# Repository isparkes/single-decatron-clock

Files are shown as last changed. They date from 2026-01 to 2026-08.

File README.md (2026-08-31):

# Single Decatron Clock Firmware

Firmware for a clock built around a single Decatron (Dekatron) cold-cathode
gas-discharge tube — a 1950s-era 30-position counting tube repurposed here as
an analogue-style hours/minutes/seconds display.

Current software version: `4`

See [`SPECIFICATION.md`](SPECIFICATION.md) for the full hardware/firmware
specification and [`DecatronClockFirmware/USER_MANUAL.md`](DecatronClockFirmware/USER_MANUAL.md)
for end-user documentation of the web interface and configuration options.

## Hardware overview

An ESP8266 (Wemos D1 Mini) drives a Decatron tube through a two-guide
stepping scheme, decoding a rotary glow position from three interrupt phases
per step (30 pin-steps per revolution). The device runs as either a
standalone clock (NTP with DS1307 RTC fallback) or as an I2C slave to a
master clock — in this repo's current configuration, an
[ENIAC Nixie clock](../eniac-firmware) — which pushes wall-clock time and
blanking state once per second.

## Highlights

Some of the more interesting problems this firmware solves:

- **Single-interrupt display multiplexing with per-dot brightness weighting**
  — one `timer1` ISR steps the tube through all 30 positions, comparing the
  current pin against three independently tracked display targets
  (hours/minutes/seconds) and re-arming itself with a dwell count scaled 60×,
  15×, or 5× the base "off" duration. Three dots glow simultaneously at
  three distinct brightness levels from a single timer, with no separate
  PWM channel per dot.
- **Self-homing via a swappable ISR** — at boot the firmware runs a slow
  *scanning* interrupt handler that free-runs the tube until a physical index
  sense pin fires, then hot-swaps `timer1`'s callback to the normal *display*
  handler. The index trigger continues correcting drift at every revolution,
  so the tube's absolute glow position never has to be assumed — it's always
  physically re-derived.
- **Graceful multi-source time arbitration** — an I2C slave callback
  (`ICACHE_RAM_ATTR`, interrupt-context, exactly 4 bytes, no blocking) accepts
  push updates from a master clock once per second and overrides local state;
  if a second passes with no packet, the display falls back to its own
  NTP-derived clock and locally computed blanking without a hiccup. All the
  actual decision logic runs in the main loop — the ISR only stashes bytes
  into `volatile` buffers.
- **Layered blanking with escalating button override** — day/week schedule,
  PIR motion timeout, and an explicit remote "blanked" command from the I2C
  master all compete to blank the tube, and a single button independently
  suppresses all of them: press once to hold the display on for a minute,
  twice in quick succession for an hour, three times for a day, with the
  press count decoded from timing between presses.
- **Perceptually-tuned spin-up ramp** — coming out of blanking, the HV supply
  re-enables and the multiplex dwell count ramps back down from a 250,000-count
  "off" dwell to a 1,000-count "on" dwell at one of three configurable rates,
  so the tube visibly fades in rather than snapping to full brightness.
- **Self-describing status page** — the root web page live-scans all 128 I2C
  addresses to report connected peripherals, and encodes overall device
  health (WiFi / NTP / SPIFFS / OTA-available / auth / debug) as a compact
  single-character status string, alongside uptime and tube-on-time
  statistics persisted to SPIFFS.
- **Zero-touch provisioning and recovery** — first boot (or a factory reset
  triggered by holding the button at power-up) opens a WiFiManager captive
  portal; once configured, the device is reachable by mDNS hostname, supports
  OTA updates gated on available flash headroom, and independently exposes
  WiFi-only, config-only, and full-factory reset endpoints.

## Repository layout

| Path | Description |
|---|---|
| [`DecatronClockFirmware`](DecatronClockFirmware) | Main Arduino sketch and supporting modules (display ISR, I2C slave, web server, NTP, RTC, SPIFFS config, button handling, debug logging). |
| [`decatron_clock_test`](decatron_clock_test) | Standalone bench sketch for exercising the Decatron tube stepping logic in isolation. |

## Building

This is an Arduino sketch targeting the ESP8266 core.

```bash
# Board: Lolin/Wemos D1 Mini, 160 MHz, Flash 4MB (FS: 2MB, OTA: ~1MB)
# Open DecatronClockFirmware/DecatronClockFirmware.ino in the Arduino IDE
# or build with arduino-cli:
arduino-cli compile --fqbn esp8266:esp8266:d1_mini DecatronClockFirmware
arduino-cli upload  --fqbn esp8266:esp8266:d1_mini -p <port> DecatronClockFirmware
```

Dependencies: [`TimeLib`](https://github.com/michaelmargolis/arduino_time),
[`WiFiManager`](https://github.com/tzapu/WiFiManager), and the ESP8266
Arduino core (`ESP8266WiFi`, `ESP8266WebServer`, `ESP8266HTTPUpdateServer`,
`ESP8266mDNS`, `LittleFS`/`SPIFFS`, `Wire`).

## Documentation

- [`SPECIFICATION.md`](SPECIFICATION.md) — full hardware/firmware specification, including the I2C protocol, GPIO map, and configuration parameters
- [`DecatronClockFirmware/USER_MANUAL.md`](DecatronClockFirmware/USER_MANUAL.md) / [`USER_MANUAL.html`](DecatronClockFirmware/USER_MANUAL.html) — end-user manual

## License

This project is licensed under a strict Attribution-NonCommercial license — see
[`LICENSE`](LICENSE) for the full text. In short: attribution to Ian Sparkes is required, and
commercial use is not permitted without a separate written license.

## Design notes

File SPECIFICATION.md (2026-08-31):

# Single Decatron Clock Firmware Specification

**Version:** 4
**Platform:** ESP8266 (Lolin/Wemos D1 Mini)
**Framework:** Arduino (ESP8266 Arduino Core)

---

## 1. Overview

The Single Decatron Clock firmware drives a single Decatron (Dekatron) gas-discharge tube clock. A Decatron is a cold-cathode tube with 30 cathode positions (10 main cathodes plus 20 guide cathodes). The tube glows at one or more positions simultaneously; display intensity is controlled by the dwell time of the interrupt-driven scanning loop.

The firmware operates in two modes:

- **Standalone mode** — the device sources its own time from NTP over WiFi, with fallback to an onboard DS1307 RTC.
- **I2C slave mode (current)** — the device acts as an I2C slave to a master clock (e.g. Eniac/LTC-ESP32). Time, blanking state, and display mode are pushed to it once per second. NTP remains active as a fallback time source; the RTC is not accessible while the I2C bus is in slave mode.

### 1.1 Key Features

- Decatron tube display: simultaneous hours, minutes, and seconds dots at configurable brightnesses
- I2C slave receiver: accepts time and control data from a master clock once per second
- NTP time synchronisation over WiFi (fallback when no I2C master is present)
- Configurable day/week blanking schedules
- PIR motion detection with configurable timeout
- Button-triggered blanking suppression (1 minute / 1 hour / 1 day)
- Adaptive brightness via LDR (light-dependent resistor)
- Optional seconds flashing
- Web configuration interface with HTTP Basic Authentication
- Over-the-air (OTA) firmware updates
- mDNS hostname resolution
- SPIFFS-backed persistent configuration and uptime statistics
- Factory reset via button held at boot

---

## 2. Hardware

### 2.1 Microcontroller

| Component | Specification |
|---|---|
| MCU | ESP8266 (Lolin/Wemos D1 Mini) |
| Clock | 160 MHz |
| Flash | 4 MB (FS: 2 MB, OTA: ~1 MB) |
| Framework | Arduino (ESP8266 Arduino Core) |

### 2.2 GPIO Assignments

| Signal | Pin | GPIO | Description |
|---|-----|---|---|
| Guide1 | D7 | GPIO13 | Decatron guide 1 (G1) |
| Guide2 | D8 | GPIO15 | Decatron guide 2 (G2) |
| Index | D6 | GPIO12 | Decatron index sense (K0 high when glow at K0) |
| HVEnable | D5 | GPIO14 | High-voltage supply enable (HIGH = on) |
| PIR | D4 | GPIO2 | PIR motion sensor input |
| Button1 | D3 | GPIO0 | User input button (active low) |
| LDR | A0 | ADC0 | Light-dependent resistor (analogue) |
| I2C SDA | D2 | GPIO4 | I2C data (slave to master clock) |
| I2C SCL | D1 | GPIO5 | I2C clock (slave to master clock) |

> **Note:** In I2C slave mode the SDA/SCL pins (D2/D1) cannot simultaneously be used to communicate with the onboard RTC. The RTC is therefore bypassed.

### 2.3 Peripherals

| Peripheral | Interface | Address / Notes |
|---|---|---|
| DS1307 RTC | I2C | 0x68 — bypassed in slave mode |
| Master clock (Eniac) | I2C slave | 0x6A (106) — this device |
| LDR | Analogue | A0 |
| PIR sensor | Digital | D4, optional |

---

## 3. Display

### 3.1 Decatron Tube

A Decatron has 30 addressable positions driven via a two-guide stepping scheme. Each step consists of three phases:

| Phase | Guide1 | Guide2 | Effect |
|---|---|---|---|
| 0 | LOW | LOW | Resting (at current cathode) |
| 1 | HIGH | LOW | Step via G1 |
| 2 | LOW | HIGH | Step via G2 |

Three phase steps advance the glow by one main cathode position (1/10th of the tube). Ten main cathodes × 3 phases = 30 total pin-steps per revolution.

### 3.2 Display Values

Time is mapped to tube positions as follows:

| Value | Mapping | Tube position range |
|---|---|---|
| Hours | `((h % 12) * 60 + m) * 30.0 / 720` | 0–29 (12-hour) |
| Minutes | `m / 2` | 0–29 |
| Seconds | `s / 2` | 0–29 |

Three dots are shown simultaneously. Dwell-time weighting controls relative brightness:

| Dot | Multiplier (× base mux count) | Relative brightness |
|-----|---|---|
| Hours | 60× | Brightest |
| Minutes | 15× | Medium |
| Seconds | 5× | Dimmest |

The base mux count (`INT_MUX_COUNTS_ON = 1000`, units of 0.2 µs at TIM_DIV16 / 80 MHz) sets the off-state dwell; active positions dwell longer.

### 3.3 Startup Scan

On power-up the firmware runs a slow scanning interrupt (`displayUpdateScanning`) at `INT_MUX_COUNTS_OFF × 2` to locate the index mark and home the tube before switching to normal display.

### 3.4 Display Rotation

`current_config.displayRotate` (0–9) offsets the index correction point so the K0 position can be aligned to any desired clock position.

### 3.5 Seconds Flash

When `current_config.flashSeconds` is set:
- The minutes dot is hidden for the first 500 ms of each second.
- The seconds dot alternates on/off every 100 ms.

### 3.6 Blanking

When `blanked` is true the HV supply is disabled (`HVEnable = LOW`) and the mux count ramps up toward `INT_MUX_COUNTS_OFF`. When un-blanked, HV is enabled and the mux count ramps back down to `INT_MUX_COUNTS_ON` at a rate set by `spinUpVal`.

---

## 4. I2C Slave Protocol

The device listens at I2C address **106 (0x6A)** on SDA = D2 (GPIO4), SCL = D1 (GPIO5).

### 4.1 Receive Packet (master → slave)

Sent by the master once per second. Exactly 4 bytes:

| Byte | Field | Range | Description |
|---|---|---|---|
| 1 | Hours | 0–23 | Current hour (24-hour) |
| 2 | Minutes | 0–59 | Current minute |
| 3 | Seconds | 0–59 | Current second |
| 4 | Control | — | See below |

#### Control Byte

| Bit(s) | Mask | Field | Description |
|---|---|---|---|
| 0 | `0x01` | Blanked | 1 = master requests display blank |
| 1–4 | `0x1E` | Primary mode | Master's current display mode (reserved for future use) |
| 5–7 | — | Reserved | Ignored |

### 4.2 Behaviour on Receipt

The `onI2CReceive` callback (runs in interrupt context) stores the received bytes in volatile variables and sets `i2cDataReceived = true`. In the main loop, when the flag is set:

1. `displayHours`, `displayMinsPrep`, and `displaySecsPrep` are recalculated from the received h/m/s.
2. `blanked` is set from control bit 0, overriding any local NTP-based blanking decision.

### 4.3 Fallback

If no I2C packet has been received since the last second tick, the display continues to be driven by the NTP-derived internal time and local blanking logic.

---

## 5. Time Sources

### 5.1 Priority

| Priority | Source | Condition |
|---|---|---|
| 1 | I2C master | Packet received in current loop iteration |
| 2 | NTP | WiFi connected and NTP valid |
| 3 | Internal (TimeLib) | No connectivity; retains last set time |

### 5.2 RTC

A DS1307 RTC at I2C address 0x68 is supported in standalone mode only. While the I2C bus is configured as slave (address 0x6A), the device cannot act as I2C master and the RTC is bypassed (`useRTC = false`).

### 5.3 NTP

| Parameter | Default |
|---|---|
| NTP pool | Configured at first boot / via web UI |
| Update interval | Configurable |
| Timezone | POSIX TZ string, configurable |

NTP updates are requested at startup and periodically by the async NTP component. A successful update also sets the RTC in standalone mode.

---

## 6. Blanking

Blanking disables the HV supply and fades the mux count to `INT_MUX_COUNTS_OFF`. Multiple sources can independently trigger blanking.

### 6.1 Blanking Sources

| Source | Trigger | Notes |
|---|---|---|
| I2C master | Control byte bit 0 set | Overrides local logic immediately |
| Day/schedule | `current_config.dayBlanking` | See modes below |
| PIR timeout | No motion within `pirTimeout` seconds | When PIR sensor installed |
| Button suppression | Active suppress period | Overrides day/schedule and PIR |

### 6.2 Day Blanking Modes

| Value | Name | Description |
|---|---|---|
| 0 | Never | Always on (default) |
| 1 | Weekend | Blank all day Saturday and Sunday |
| 2 | Weekday | Blank all day Monday–Friday |
| 3 | Always | Always blank |
| 4 | Hours | Blank between `blankHourStart` and `blankHourEnd` every day |
| 5 | Weekend or Hours | Mode 4 on weekdays, mode 1 on weekends |
| 6 | Weekday or Hours | Mode 4 on weekends, mode 2 on weekdays |
| 7 | Weekend and Hours | Mode 4 only during weekends |
| 8 | Weekday and Hours | Mode 4 only during weekdays |

### 6.3 PIR Motion Detection

When a PIR sensor is installed, native day/schedule blanking is disabled. The tube blanks after `pirTimeout` seconds of no motion (default 300 s, range 60–3600 s). Motion is detected by counting consecutive loop iterations where the PIR pin is HIGH; at least half the impressions-per-second must be active to count as a valid detection.

### 6.4 Button Blanking Suppression

A button press during a blanked period suppresses blanking. Successive rapid presses increase the suppression duration:

| Presses | Duration |
|---|---|
| 1 | 1 minute |
| 2 | 1 hour |
| 3 | 1 day |

---

## 7. Configuration

### 7.1 Stored Parameters (SPIFFS)

| Parameter | Type | Default | Description |
|---|---|---|---|
| `ntpPool` | String | — | NTP server hostname |
| `ntpUpdateInterval` | int | — | NTP poll interval (s) |
| `tzs` | String | — | POSIX timezone string |
| `showSeconds` | bool | — | Show seconds dot |
| `flashSeconds` | bool | — | Flash seconds dot |
| `dayBlanking` | byte | 0 | Blanking schedule mode |
| `blankHourStart` | byte | 0 | Blanking start hour |
| `blankHourEnd` | byte | 7 | Blanking end hour |
| `pirTimeout` | int | 300 | PIR inactivity timeout (s) |
| `usePIRPullup` | bool | — | Enable PIR pin internal pull-up |
| `displayRotate` | byte | 0–9 | Index position offset |
| `spinUpSpeed` | byte | 1 | Spin-up speed (0=slow, 1=medium, 2=fast) |
| `webAuthentication` | bool | true | Require HTTP auth |
| `webUsername` | String | admin | Web UI username |
| `webPassword` | String | setup | Web UI password |
| `testMode` | bool | true | Enable test/diagnostic mode |

### 7.2 Persistent Statistics

| Field | Description |
|---|---|
| `uptimeMins` | Total uptime in minutes |
| `tubeOnTimeMins` | Minutes the tube has been unblanked |

Statistics are written to SPIFFS once per day and on explicit save.

### 7.3 Factory Reset

Factory reset is triggered by:
- Holding Button1 at boot.
- The `/resetall` or `/resetoptions` web endpoint.

Reset restores all parameters to defaults and saves to SPIFFS.

---

## 8. Web Interface

The device hosts an HTTP server on port 80. All pages except the root require HTTP Basic Authentication when enabled.

### 8.1 Endpoints

| Path | Description |
|---|---|
| `/` | Status and clock information |
| `/time` | Set time manually |
| `/resetoptions` | Reset configuration to defaults |
| `/resetwifi` | Clear WiFi credentials and restart |
| `/resetall` | Full factory reset |
| `/update` | OTA firmware upload (admin / update) |

### 8.2 mDNS

The device advertises itself via mDNS as `http://<hostname>.local` with an HTTP service on port 80.

---

## 9. WiFi

On first boot (or after a WiFi reset) the device starts a WiFi captive portal AP named **decatron** with passphrase **SetMeUp!**. The portal times out after 60 seconds. Once credentials are saved they are used on all subsequent boots. Auto-reconnect is enabled; a dropped connection is retried once per hour.

---

## 10. Firmware Updates

OTA updates are available at `/update` (credentials: admin / update) when the compiled sketch size is less than half the available flash. Updates are served via `ESP8266HTTPUpdateServer`.

---

## 11. Spin-Up Speeds

The mux count ramps from `INT_MUX_COUNTS_OFF` (250 000) down to `INT_MUX_COUNTS_ON` (1 000) at startup and after un-blanking. The ramp rate is controlled by `spinUpVal`:

| Mode | `spinUpVal` | Ramp character |
|---|---|---|
| Slow | 200 | Gradual |
| Medium (default) | 100 | Normal |
| Fast | 50 | Rapid |

---

## 12. Software Architecture

### 12.1 Interrupt Handler

`displayUpdate()` runs on `timer1` (TIM_DIV16, single-shot). Each call:
1. Advances `phaseStep` (0→1→2→0).
2. On phase rollover, advances `digitStep` (0–9).
3. Calls `G_step(phaseStep)` to assert Guide1/Guide2.
4. Compares `pinStep = digitStep * 3 + phaseStep` against the three display targets.
5. Sets the next timer alarm to the dwell count for the active dot (or the base count if none match).

`indexMarkTrigger()` fires on the falling edge of the Index pin and corrects `digitStep` to align the tube to `displayRotate`.

### 12.2 Main Loop Cadence

| Interval | Action |
|---|---|
| Every 10 ms | Main loop tick: handle web server, PIR sampling, flash logic, I2C data application, HV/mux ramp |
| Once per second | `performOncePerSecondProcessing`: blanking check, NTP poll, display value update |
| Once per minute | `performOncePerMinuteProcessing`: uptime stats, connectivity log |
| Once per hour | `performOncePerHourProcessing`: WiFi reconnect attempt |
| Once per day | `performOncePerDayProcessing`: save stats to SPIFFS |

### 12.3 I2C Slave Callback

`onI2CReceive(int numBytes)` runs in interrupt context (`ICACHE_RAM_ATTR`). It reads exactly 4 bytes into volatile buffers and sets `i2cDataReceived`. All non-trivial processing occurs in the main loop.

### 12.4 Component Files

| File | Responsibility |
|---|---|
| `DecatronClockFirmware.ino` | Main sketch: display ISR, setup, loop, time management, blanking, I2C slave |
| `ClockDefs.h` | Pin assignments, constants, blanking mode enums |
| `SPIFFS.cpp/h` | Persistent config and stats (ArduinoJson 5) |
| `ESP_DS1307.cpp/h` | DS1307 RTC driver (I2C master; unused in slave mode) |
| `NtpAsync.cpp/h` | Asynchronous NTP client |
| `HtmlServer.cpp/h` | HTTP server, OTA, mDNS, HTML helpers |
| `ClockUtils.cpp/h` | String/debug utilities |
| `ClockButton.cpp/h` | Debounced button handler |
| `DebugManager.cpp/h` | Serial debug output |

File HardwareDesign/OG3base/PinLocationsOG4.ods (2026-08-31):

 |  |  |  |  | Pin Unadjusted |  | Pin Adjusted
 |  |  | Radians | Rad Adj | X | Y | X | y | Pin | Function
1 | 0 | 0 | 0 | 0.392699081698724 | 0 | -8.75 | 3.34848003319454 | -8.08394590947376 | 1 | INDEX
2 | 1 | 45 | 0.785398163397448 | 1.17809724509617 | 6.18718433538229 | -6.18718433538229 | 8.08394590947376 | -3.34848003319454 | 2 | NC
3 | 2 | 90 | 1.5707963267949 | 1.96349540849362 | 8.75 | -5.35782974626967E-16 | 8.08394590947376 | 3.34848003319453 | 3 | ANODE
4 | 3 | 135 | 2.35619449019234 | 2.74889357189107 | 6.18718433538229 | 6.18718433538229 | 3.34848003319454 | 8.08394590947376 | 4 | G1
5 | 4 | 180 | 3.14159265358979 | 3.53429173528852 | 1.07156594925393E-15 | 8.75 | -3.34848003319453 | 8.08394590947376 | 5 | NC
6 | 5 | 225 | 3.92699081698724 | 4.31968989868597 | -6.18718433538229 | 6.18718433538229 | -8.08394590947376 | 3.34848003319453 | 6 | G2
7 | 6 | 270 | 4.71238898038469 | 5.10508806208341 | -8.75 | 1.6073489238809E-15 | -8.08394590947376 | -3.34848003319454 | 7 | NC
8 | 7 | 315 | 5.49778714378214 | 5.89048622548086 | -6.18718433538229 | -6.18718433538229 | -3.34848003319453 | -8.08394590947376 | 8 | K1-9
#pins | 8 |  |  | Deg per pin | 45
degrees rotated | 22.5
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

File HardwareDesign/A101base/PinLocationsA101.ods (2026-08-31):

 |  |  |  |  | Pin Unadjusted |  | Pin Adjusted
 |  |  | Radians | Rad Adj | X | Y | X | y | Pin | Function
1 | 0 | 0 | 0 | 5.39044939478449 | 0 | -12.5 | -9.7348856658788 | -7.84104591698502 | 13 | K1
2 | 1 | 27.6923076923077 | 0.483321946706122 | 5.87377134149061 | 5.80903965054711 | -11.0682003206651 | -4.97589744121533 | -11.4669283007485 | 12 | K2
3 | 2 | 55.3846153846154 | 0.966643893412244 | 6.35709328819673 | 10.2872983236707 | -7.10080933413945 | 0.923008921165805 | -12.4658756022771 | 11 | K3
4 | 3 | 83.0769230769231 | 1.44996584011837 | 6.84041523490285 | 12.4088609262257 | -1.50670850319154 | 6.61046506317119 | -10.6090410334108 | 10 | G2
5 | 4 | 110.769230769231 | 1.93328778682449 | 7.32373718160898 | 11.6877030335677 | 4.4325610880317 | 10.7835433239441 | -6.32180301659429 | 9 | K4
6 | 5 | 138.461538461538 | 2.41660973353061 | 7.8070591283151 | 8.28903322800994 | 9.35638435213876 | 12.4862417649863 | -0.58631611466134 | 8 | ANODE
7 | 6 | 166.153846153846 | 2.89993168023673 | 8.29038107502122 | 2.99144580359448 | 12.1367727178256 | 11.3284926931957 | 5.28348874326536 | 7 | K5
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

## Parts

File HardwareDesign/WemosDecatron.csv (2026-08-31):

Id | Designator | Package | Quantity | Designation | Supplier and ref
1 | JP1 | SOLDER-JUMPER | 1 | HV Test Enable
2 | R16,R9,R11 | R-0207_2V | 3 | 470k
3 | Q5 | TO-92_inline_2N7000 | 1 | 2N7000
4 | W8 | TESTPAD_P1-13 | 1 | VIN
5 | C8,C6,C12,C14 | C025-024X044 | 4 | 100nF
6 | Q2 | TO-220-3_H | 1 | IRF640
7 | J2 | Header_MA08-1 | 1 | Conn_01x08
8 | W7 | TESTPAD_P1-13 | 1 | 400V
9 | U3 | TO-220-3_H | 1 | L7805
10 | D1 | Diode_DO-41_SOD81_Vertical_AnodeUp | 1 | UF4007
11 | D2 | Diode_DO-41_SOD81_Vertical_AnodeUp | 1 | 1N5819
12 | H4,H3,H2,H1 | MountingHole_3.2mm_M3 | 4 | MountingHole
13 | C13,C2,C1,C4,C3 | CP_Radial_D5.0mm_P2.50mm | 5 | 1uF 250V
14 | D3,D4,D5,D6,D7 | Diode_DO-41_1N4001 | 5 | UF4007
15 | W6 | TESTPAD_P1-13 | 1 | 55V
16 | U1 | optocoupler-DIL04 | 1 | EL817
17 | L1 | Inductor-100mH | 1 | 100uH
18 | Y1 | Crystal_DS10_d1.0mm_l4.3mm_Vertical | 1 | Crystal
19 | C11 | C025-024X044 | 1 | 330pF
20 | R2,R6,R7,R8,R10 | R-0207_2V | 5 | 10k
21 | R3 | R-0207_2V | 1 | 1k
22 | R4 | R-0207_2V | 1 | 390k
23 | R5 | R-0207_2V | 1 | 2k7
24 | Q1 | TO-92_inline_2N3906 | 1 | 2N3906
25 | R1 | R_2W | 1 | 0R18 2W
26 | U5 | DS1307_DIL8 | 1 | DS1307+
27 | U4 | MC34063_DIL8 | 1 | MC34063A
28 | U2 | WeMos_D1_mini_board_flipped | 1 | WeMos_mini
29 | BT1 | CR1220-CoinCell | 1 | Battery_Cell
30 | W1 | TESTPAD_P1-13 | 1 | 5V
31 | W2,W3 | TESTPAD_P1-13 | 2 | GND
32 | W4 | TESTPAD_P1-13 | 1 | 140V
33 | J3 | Header_MA02-1 | 1 | CONN_01X02
34 | C10,C9,C7 | C_Radial_D6.3_L11.2_P2.5 | 3 | 220uF
35 | RV1 | Potentiometer_Trimmer_Bourns_3296X | 1 | 1k
36 | J1 | Header_MA05-1 | 1 | Conn_01x05
37 | Q3,Q4 | TO-92_inline_MPSA42 | 2 | MPSA42
38 | R12 | R-0207_2V | 1 | 33k
39 | R13,R14 | R-0207_2V | 2 | 47k
40 | R15 | R-0207_2V | 1 | 220k
41 | W5 | TESTPAD_P1-13 | 1 | 110V

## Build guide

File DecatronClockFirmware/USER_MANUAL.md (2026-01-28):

# Single Decatron Clock - User Manual

**Firmware Version 4**

---

## Table of Contents

1. [Introduction](#introduction)
2. [Hardware Overview](#hardware-overview)
3. [Initial Setup](#initial-setup)
4. [Understanding the Display](#understanding-the-display)
5. [Web Interface](#web-interface)
6. [Configuration Options](#configuration-options)
7. [Blanking and Power Management](#blanking-and-power-management)
8. [Time Sources](#time-sources)
9. [Button Functions](#button-functions)
10. [Troubleshooting](#troubleshooting)
11. [Technical Specifications](#technical-specifications)

---

## Introduction

The Single Decatron Clock is a unique timepiece that uses a Decatron tube - a vintage gas discharge counting tube - to display the current time. The Decatron tube contains 10 cathodes arranged in a circle, and glowing dots rotate around the tube to indicate hours, minutes, and optionally seconds.

The clock synchronizes time automatically via the internet using NTP (Network Time Protocol) and includes a battery-backed real-time clock for maintaining time during power outages.

### Key Features

- **Automatic time synchronization** via NTP
- **Battery-backed RTC** for time persistence during power loss
- **Web-based configuration** interface
- **Configurable display blanking** based on time of day or motion detection
- **Optional PIR motion sensor** support
- **Over-the-air firmware updates**
- **Multiple timezone support**

---

## Hardware Overview

### Components

| Component | Description |
|---|---|
| Decatron Tube | 10-cathode gas discharge display tube |
| ESP8266 (D1 Mini) | WiFi-enabled microcontroller |
| DS1307 RTC | Battery-backed real-time clock (optional but recommended) |
| PIR Sensor | Motion detector for auto-blanking (optional) |
| Push Button | Factory reset and future functions |

### Pin Connections

| Pin | Function |
|-----|---|
| D7 | Decatron Guide 1 (G1) |
| D8 | Decatron Guide 2 (G2) |
| D6 | Index Detection |
| D5 | High Voltage Enable |
| D4 | PIR Motion Sensor (optional) |
| D3 | Push Button |
| D1 | I2C Clock (SCL) for RTC |
| D2 | I2C Data (SDA) for RTC |

---

## Initial Setup

### Step 1: Power On

When powered on for the first time (or after a factory reset), the clock will create a WiFi access point for configuration.

### Step 2: Connect to WiFi Configuration Portal

1. On your phone or computer, look for a WiFi network named **"decatron"**
2. Connect to this network using password: **SetMeUp!**
3. A configuration portal should open automatically
4. If it doesn't open automatically, navigate to `192.168.4.1` in your web browser

### Step 3: Configure WiFi

1. Select your home WiFi network from the list
2. Enter your WiFi password
3. Click **Save**
4. The clock will restart and connect to your network

### Step 4: Access the Web Interface

Once connected to your network, you can access the clock's web interface:

- **By hostname:** `http://decatron.local` (if mDNS is supported on your network)
- **By IP address:** Check your router's connected devices list to find the clock's IP address

### Step 5: Configure Time Settings

1. Navigate to the **Time Server** page
2. Select your timezone (see [Timezone Configuration](#timezone-configuration))
3. The clock will automatically sync time from the NTP server

---

## Understanding the Display

The Decatron tube displays time using up to three glowing dots that rotate around the tube's circular display:

### Display Elements

| Dot | Represents | Position Calculation |
|-----|---|---|
| Hours | Current hour (12-hour format) | Hour position on a 30-point scale |
| Minutes | Current minutes | Minutes divided by 2 (0-29) |
| Seconds | Current seconds (optional) | Seconds divided by 2 (0-29) |

### Reading the Time

The display works similar to an analog clock face:
- The **hours dot** shows the current hour
- The **minutes dot** shows the current minutes
- The **seconds dot** (if enabled) shows the current seconds

Since the Decatron has 10 cathodes with 3 phases each (30 positions total), the time is mapped to these 30 positions:
- Hours are converted from 24-hour to 12-hour format
- Minutes and seconds are divided by 2 to fit the 30-position display

### Flash Mode

When flash mode is enabled:
- The seconds dot blinks on and off
- The minutes dot blinks alternately every 500ms
- This helps distinguish between the different time elements

---

## Web Interface

The clock provides a web-based interface for configuration and status monitoring.

### Default Login Credentials

If authentication is enabled:
- **Username:** admin
- **Password:** setup

### Main Pages

#### Summary Page (/)

The home page displays:
- **WiFi Status:** Connected network and signal strength
- **Current Time:** Local time and timezone
- **System Uptime:** How long the clock has been running
- **NTP Status:** Last sync time and next update
- **Clock Information:** Motion sensor status, time source, RTC status
- **System Information:** ESP8266 details, memory usage
- **I2C Devices:** Detected devices on the I2C bus

**Status Indicators:**
| Letter | Uppercase | Lowercase |
|---|---|---|
| W | WiFi connected | WiFi disconnected |
| N | NTP time valid | NTP time invalid |
| S | SPIFFS mounted | SPIFFS error |
| U | OTA update available | OTA unavailable |
| A | Authentication enabled | Authentication disabled |
| D | Debug mode on | Debug mode off |

#### Time Server Page (/time)

Configure NTP and timezone settings:
- NTP server pool selection
- Update interval
- Timezone string

#### Clock Configuration Page (/clockconfig)

Configure display and blanking options:
- Show/hide seconds
- Flash mode on/off
- Display rotation calibration
- Spin-up speed
- Blanking schedules
- Motion detector settings
- Authentication settings

#### Utility Page (/utility)

Maintenance functions:
- Reset WiFi settings only
- Reset configuration only
- Reset all settings (factory reset)
- Force NTP update
- Firmware update (OTA)
- Enable debug output

---

## Configuration Options

### General Display Settings

| Setting | Options | Description |
|---|---|---|
| Show Seconds | On / Off | Display the seconds dot |
| Flash Seconds/Minutes | Flash / Fixed | Enable blinking mode |
| Display Rotation | 0-9 | Calibrate physical tube alignment |
| Spin-up Speed | Slow / Medium / Fast | How quickly display transitions |

### Display Rotation Calibration

If the display appears rotated (12 o'clock is not at the top):
1. Go to **Clock Configuration**
2. Adjust the **Display Rotation** value (0-9)
3. Each increment rotates the display by one cathode position
4. Save and observe the display until aligned correctly

### Spin-up Speed

Controls how fast the dots move during position changes:
| Speed | Delay | Best For |
|---|---|---|
| Slow | 200ms | Visual effect, gentle transition |
| Medium | 100ms | Balanced performance |
| Fast | 50ms | Quick updates, minimal motion |

---

## Blanking and Power Management

The clock can automatically turn off (blank) the display based on time schedules or motion detection.

### Time-Based Blanking Modes

| Mode | Description |
|---|---|
| Never blank | Display always on |
| Blank all day on weekends | Off on Saturday and Sunday |
| Blank all day on weekdays | Off Monday through Friday |
| Blank always | Display always off |
| Blank hours - every day | Blank during set hours daily |
| Blank hours - weekdays only | Blank during hours Mon-Fri |
| Blank hours - weekends only | Blank during hours Sat-Sun |
| Blank hours - week + all weekends | Blank hours on weekdays, all day on weekends |

### Blanking Hour Configuration

When using hour-based blanking:
- **Blank From:** Start hour (0-23)
- **Blank To:** End hour (0-23)

Example: To blank from 11 PM to 7 AM:
- Blank From: 23
- Blank To: 7

### Motion Detector (PIR)

If a PIR motion sensor is connected:

1. The display turns on when motion is detected
2. The display blanks after the timeout period with no motion
3. Motion detection overrides time-based blanking

**Motion Timeout Options:**
- 60 seconds (1 minute)
- 120 seconds (2 minutes)
- 300 seconds (5 minutes)
- 600 seconds (10 minutes)
- 1800 seconds (30 minutes)
- 3600 seconds (1 hour)

**PIR Pullup Setting:**
- Enable if your PIR sensor requires an internal pull-up resistor
- Most PIR modules have their own pull-up and don't need this

---

## Time Sources

The clock uses multiple time sources with automatic fallback:

### Priority Order

1. **NTP (Network Time Protocol)** - Primary source
   - Syncs time over the internet
   - Default server: pool.ntp.org
   - Update interval: ~2 hours (7261 seconds)

2. **DS1307 RTC** - Backup source
   - Battery-backed real-time clock
   - Maintains time during power outages
   - Automatically updated when NTP syncs

3. **Internal ESP8266 Time** - Fallback
   - Used only when NTP and RTC unavailable
   - May drift over time

### Timezone Configuration

The clock uses POSIX timezone strings. Common examples:

| Location | Timezone String |
|---|---|
| UK (GMT/BST) | `GMT0BST,M3.5.0/1,M10.5.0` |
| Central Europe (CET/CEST) | `CET-1CEST,M3.5.0,M10.5.0/3` |
| US Eastern (EST/EDT) | `EST5EDT,M3.2.0,M11.1.0` |
| US Pacific (PST/PDT) | `PST8PDT,M3.2.0,M11.1.0` |
| Australia Eastern (AEST/AEDT) | `AEST-10AEDT,M10.1.0,M4.1.0/3` |

The format is: `STD offset DST,start,end`

For a comprehensive list, see: https://github.com/nayarsystems/posix_tz_db/blob/master/zones.csv

### NTP Update Interval

- **Default:** 7261 seconds (~2 hours)
- **Range:** 60 to 86400 seconds
- The default avoids round-hour sync times to distribute server load

---

## Button Functions

The clock has a single push button (connected to pin D3):

### Factory Reset

To perform a factory reset:
1. Power off the clock
2. Press and hold the button
3. Power on the clock while holding the button
4. Continue holding for at least 1 second
5. Release the button
6. The clock will reset all settings and enter WiFi configuration mode

---

## Troubleshooting

### Clock Won't Connect to WiFi

1. Ensure you're entering the correct WiFi password
2. Check that your router is using 2.4 GHz (ESP8266 doesn't support 5 GHz)
3. Try moving the clock closer to your router
4. Perform a factory reset and reconfigure

### Display Shows Wrong Time

1. Check the timezone configuration in the web interface
2. Force an NTP update from the Utility page
3. Verify your internet connection is working
4. If you have an RTC, ensure the battery is not depleted

### Display Appears Rotated

1. Go to Clock Configuration
2. Adjust the Display Rotation value
3. Try different values (0-9) until 12 o'clock is at the top

### Cannot Access Web Interface

1. Ensure you're on the same network as the clock
2. Try accessing by IP address instead of hostname
3. Check if your router shows the clock as connected
4. Wait a few minutes after power-on for the clock to fully boot

### Display is Dim or Not Working

1. Check all cable connections
2. Verify the high-voltage power supply is working
3. Check that blanking is not enabled
4. Move around if a PIR sensor is installed (triggers motion detection)

### NTP Sync Fails

1. Check your internet connection
2. Try a different NTP server (e.g., `time.google.com`)
3. Verify no firewall is blocking NTP (UDP port 123)
4. The clock will fall back to RTC time if available

### Status Shows 'n' (NTP Invalid)

This means NTP hasn't synced successfully. The clock will:
- Use RTC time if available
- Retry NTP sync periodically
- Check the Summary page for more details

---

## Technical Specifications

### Microcontroller
- **Platform:** ESP8266 (Lolin D1 Mini)
- **CPU Speed:** 160 MHz
- **Flash Memory:** 4 MB (2 MB filesystem)
- **WiFi:** 802.11 b/g/n (2.4 GHz)

### Display
- **Type:** Decatron gas discharge tube
- **Cathodes:** 10
- **Display Positions:** 30 (3 phases per cathode)
- **Multiplexing:** ~1000 Hz (timer interrupt driven)

### Time Accuracy
- **NTP:** Sub-second accuracy when synced
- **RTC:** Typical ±2 ppm drift (~1 minute/year)

### Power
- **Input:** 5V DC via USB
- **High Voltage:** Generated internally for Decatron

### Network Features
- **mDNS:** `decatron.local`
- **Web Server:** Port 80
- **OTA Updates:** Supported (when flash space permits)

### Configuration Storage
- **Format:** JSON
- **Location:** SPIFFS filesystem
- **File:** `/config.json`

---

## Support and Updates

For firmware updates, bug reports, and additional documentation, visit the project repository.

### Firmware Update Procedure

1. Download the latest firmware binary
2. Go to the Utility page in the web interface
3. Click "Choose File" under Firmware Update
4. Select the firmware binary file
5. Click "Update"
6. Wait for the update to complete (do not power off)
7. The clock will restart automatically

**Note:** OTA updates require sufficient free flash space. The Summary page indicates OTA availability with 'U' (available) or 'u' (unavailable).

---

*Single Decatron Clock Firmware - Version 4*

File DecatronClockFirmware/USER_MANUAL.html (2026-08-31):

# Single Decatron Clock - User Manual

Firmware Version 4

## Table of Contents

1. Introduction
2. Hardware Overview
3. Initial Setup
4. Understanding the Display
5. Web Interface
6. Configuration Options
7. Blanking and Power Management
8. Time Sources
9. Button Functions
10. Troubleshooting
11. Technical Specifications

## 1. Introduction

The Single Decatron Clock is a unique timepiece that uses a Decatron tube - a vintage gas discharge counting tube - to display the current time. The Decatron tube contains 10 cathodes arranged in a circle, and glowing dots rotate around the tube to indicate hours, minutes, and optionally seconds.

The clock synchronizes time automatically via the internet using NTP (Network Time Protocol) and includes a battery-backed real-time clock for maintaining time during power outages.

### Key Features

- Automatic time synchronization via NTP
- Battery-backed RTC for time persistence during power loss
- Web-based configuration interface
- Configurable display blanking based on time of day or motion detection
- Optional PIR motion sensor support
- Over-the-air firmware updates
- Multiple timezone support

## 2. Hardware Overview

### Components

Component | Description
Decatron Tube | 10-cathode gas discharge display tube
ESP8266 (D1 Mini) | WiFi-enabled microcontroller
DS1307 RTC | Battery-backed real-time clock (optional but recommended)
PIR Sensor | Motion detector for auto-blanking (optional)
Push Button | Factory reset and future functions

### Pin Connections

Pin | Function
D7 | Decatron Guide 1 (G1)
D8 | Decatron Guide 2 (G2)
D6 | Index Detection
D5 | High Voltage Enable
D4 | PIR Motion Sensor (optional)
D3 | Push Button
D1 | I2C Clock (SCL) for RTC
D2 | I2C Data (SDA) for RTC

## 3. Initial Setup

### Step 1: Power On

When powered on for the first time (or after a factory reset), the clock will create a WiFi access point for configuration.

### Step 2: Connect to WiFi Configuration Portal

1. On your phone or computer, look for a WiFi network named "decatron"
2. Connect to this network using password: SetMeUp!
3. A configuration portal should open automatically
4. If it doesn't open automatically, navigate to 192.168.4.1 in your web browser

### Step 3: Configure WiFi

1. Select your home WiFi network from the list
2. Enter your WiFi password
3. Click Save
4. The clock will restart and connect to your network

### Step 4: Access the Web Interface

Once connected to your network, you can access the clock's web interface:

- By hostname: http://decatron.local (if mDNS is supported on your network)
- By IP address: Check your router's connected devices list to find the clock's IP address

### Step 5: Configure Time Settings

1. Navigate to the Time Server page
2. Select your timezone (see Timezone Configuration section)
3. The clock will automatically sync time from the NTP server

## 4. Understanding the Display

The Decatron tube displays time using up to three glowing dots that rotate around the tube's circular display:

### Display Elements

Dot | Represents | Position Calculation
Hours | Current hour (12-hour format) | Hour position on a 30-point scale
Minutes | Current minutes | Minutes divided by 2 (0-29)
Seconds | Current seconds (optional) | Seconds divided by 2 (0-29)

### Reading the Time

The display works similar to an analog clock face:

- The hours dot shows the current hour
- The minutes dot shows the current minutes
- The seconds dot (if enabled) shows the current seconds

Since the Decatron has 10 cathodes with 3 phases each (30 positions total), the time is mapped to these 30 positions. Hours are converted from 24-hour to 12-hour format. Minutes and seconds are divided by 2 to fit the 30-position display.

### Flash Mode

When flash mode is enabled:

- The seconds dot blinks on and off
- The minutes dot blinks alternately every 500ms
- This helps distinguish between the different time elements

## 5. Web Interface

The clock provides a web-based interface for configuration and status monitoring.

### Default Login Credentials

If authentication is enabled:

- Username: admin
- Password: setup

### Main Pages

#### Summary Page (/)

The home page displays:

- WiFi Status: Connected network and signal strength
- Current Time: Local time and timezone
- System Uptime: How long the clock has been running
- NTP Status: Last sync time and next update
- Clock Information: Motion sensor status, time source, RTC status
- System Information: ESP8266 details, memory usage
- I2C Devices: Detected devices on the I2C bus

#### Status Indicators

Letter | Uppercase | Lowercase
W | WiFi connected | WiFi disconnected
N | NTP time valid | NTP time invalid
S | SPIFFS mounted | SPIFFS error
U | OTA update available | OTA unavailable
A | Authentication enabled | Authentication disabled
D | Debug mode on | Debug mode off

#### Time Server Page (/time)

Configure NTP and timezone settings:

- NTP server pool selection
- Update interval
- Timezone string

#### Clock Configuration Page (/clockconfig)

Configure display and blanking options:

- Show/hide seconds
- Flash mode on/off
- Display rotation calibration
- Spin-up speed
- Blanking schedules
- Motion detector settings
- Authentication settings

#### Utility Page (/utility)

Maintenance functions:

- Reset WiFi settings only
- Reset configuration only
- Reset all settings (factory reset)
- Force NTP update
- Firmware update (OTA)
- Enable debug output

## 6. Configuration Options

### General Display Settings

Setting | Options | Description
Show Seconds | On / Off | Display the seconds dot
Flash Seconds/Minutes | Flash / Fixed | Enable blinking mode
Display Rotation | 0-9 | Calibrate physical tube alignment
Spin-up Speed | Slow / Medium / Fast | How quickly display transitions

### Display Rotation Calibration

If the display appears rotated (12 o'clock is not at the top):

1. Go to Clock Configuration
2. Adjust the Display Rotation value (0-9)
3. Each increment rotates the display by one cathode position
4. Save and observe the display until aligned correctly

### Spin-up Speed

Speed | Delay | Best For
Slow | 200ms | Visual effect, gentle transition
Medium | 100ms | Balanced performance
Fast | 50ms | Quick updates, minimal motion

## 7. Blanking and Power Management

The clock can automatically turn off (blank) the display based on time schedules or motion detection.

### Time-Based Blanking Modes

Mode | Description
Never blank | Display always on
Blank all day on weekends | Off on Saturday and Sunday
Blank all day on weekdays | Off Monday through Friday
Blank always | Display always off
Blank hours - every day | Blank during set hours daily
Blank hours - weekdays only | Blank during hours Mon-Fri
Blank hours - weekends only | Blank during hours Sat-Sun
Blank hours - week + all weekends | Blank hours on weekdays, all day on weekends

### Blanking Hour Configuration

When using hour-based blanking:

- Blank From: Start hour (0-23)
- Blank To: End hour (0-23)

Example: To blank from 11 PM to 7 AM, set Blank From: 23, Blank To: 7

### Motion Detector (PIR)

If a PIR motion sensor is connected:

1. The display turns on when motion is detected
2. The display blanks after the timeout period with no motion
3. Motion detection overrides time-based blanking

#### Motion Timeout Options

- 60 seconds (1 minute)
- 120 seconds (2 minutes)
- 300 seconds (5 minutes)
- 600 seconds (10 minutes)
- 1800 seconds (30 minutes)
- 3600 seconds (1 hour)

#### PIR Pullup Setting

Enable if your PIR sensor requires an internal pull-up resistor. Most PIR modules have their own pull-up and don't need this.

## 8. Time Sources

The clock uses multiple time sources with automatic fallback:

### Priority Order

1. NTP (Network Time Protocol) - Primary source
  - Syncs time over the internet
  - Default server: pool.ntp.org
  - Update interval: ~2 hours (7261 seconds)
2. DS1307 RTC - Backup source
  - Battery-backed real-time clock
  - Maintains time during power outages
  - Automatically updated when NTP syncs
3. Internal ESP8266 Time - Fallback
  - Used only when NTP and RTC unavailable
  - May drift over time

### Timezone Configuration

The clock uses POSIX timezone strings. Common examples:

Location | Timezone String
UK (GMT/BST) | GMT0BST,M3.5.0/1,M10.5.0
Central Europe (CET/CEST) | CET-1CEST,M3.5.0,M10.5.0/3
US Eastern (EST/EDT) | EST5EDT,M3.2.0,M11.1.0
US Pacific (PST/PDT) | PST8PDT,M3.2.0,M11.1.0
Australia Eastern (AEST/AEDT) | AEST-10AEDT,M10.1.0,M4.1.0/3

The format is: STD offset DST,start,end

For a comprehensive list, see: POSIX Timezone Database (https://github.com/nayarsystems/posix_tz_db/blob/master/zones.csv)

### NTP Update Interval

- Default: 7261 seconds (~2 hours)
- Range: 60 to 86400 seconds
- The default avoids round-hour sync times to distribute server load

## 9. Button Functions

The clock has a single push button (connected to pin D3):

### Factory Reset

To perform a factory reset:

1. Power off the clock
2. Press and hold the button
3. Power on the clock while holding the button
4. Continue holding for at least 1 second
5. Release the button
6. The clock will reset all settings and enter WiFi configuration mode

## 10. Troubleshooting

### Clock Won't Connect to WiFi

1. Ensure you're entering the correct WiFi password
2. Check that your router is using 2.4 GHz (ESP8266 doesn't support 5 GHz)
3. Try moving the clock closer to your router
4. Perform a factory reset and reconfigure

### Display Shows Wrong Time

1. Check the timezone configuration in the web interface
2. Force an NTP update from the Utility page
3. Verify your internet connection is working
4. If you have an RTC, ensure the battery is not depleted

### Display Appears Rotated

1. Go to Clock Configuration
2. Adjust the Display Rotation value
3. Try different values (0-9) until 12 o'clock is at the top

### Cannot Access Web Interface

1. Ensure you're on the same network as the clock
2. Try accessing by IP address instead of hostname
3. Check if your router shows the clock as connected
4. Wait a few minutes after power-on for the clock to fully boot

### Display is Dim or Not Working

1. Check all cable connections
2. Verify the high-voltage power supply is working
3. Check that blanking is not enabled
4. Move around if a PIR sensor is installed (triggers motion detection)

### NTP Sync Fails

1. Check your internet connection
2. Try a different NTP server (e.g., time.google.com)
3. Verify no firewall is blocking NTP (UDP port 123)
4. The clock will fall back to RTC time if available

### Status Shows 'n' (NTP Invalid)

This means NTP hasn't synced successfully. The clock will:

- Use RTC time if available
- Retry NTP sync periodically
- Check the Summary page for more details

## 11. Technical Specifications

### Microcontroller

Specification | Value
Platform | ESP8266 (Lolin D1 Mini)
CPU Speed | 160 MHz
Flash Memory | 4 MB (2 MB filesystem)
WiFi | 802.11 b/g/n (2.4 GHz)

### Display

Specification | Value
Type | Decatron gas discharge tube
Cathodes | 10
Display Positions | 30 (3 phases per cathode)
Multiplexing | ~1000 Hz (timer interrupt driven)

### Time Accuracy

Source | Accuracy
NTP | Sub-second accuracy when synced
RTC | Typical ±2 ppm drift (~1 minute/year)

### Power

Specification | Value
Input | 5V DC via USB
High Voltage | Generated internally for Decatron

### Network Features

Feature | Value
mDNS | decatron.local
Web Server | Port 80
OTA Updates | Supported (when flash space permits)

### Configuration Storage

Specification | Value
Format | JSON
Location | SPIFFS filesystem
File | /config.json

## Support and Updates

For firmware updates, bug reports, and additional documentation, visit the project repository.

### Firmware Update Procedure

1. Download the latest firmware binary
2. Go to the Utility page in the web interface
3. Click "Choose File" under Firmware Update
4. Select the firmware binary file
5. Click "Update"
6. Wait for the update to complete (do not power off)
7. The clock will restart automatically

Note: OTA updates require sufficient free flash space. The Summary page indicates OTA availability with 'U' (available) or 'u' (unavailable).

Single Decatron Clock Firmware - Version 4

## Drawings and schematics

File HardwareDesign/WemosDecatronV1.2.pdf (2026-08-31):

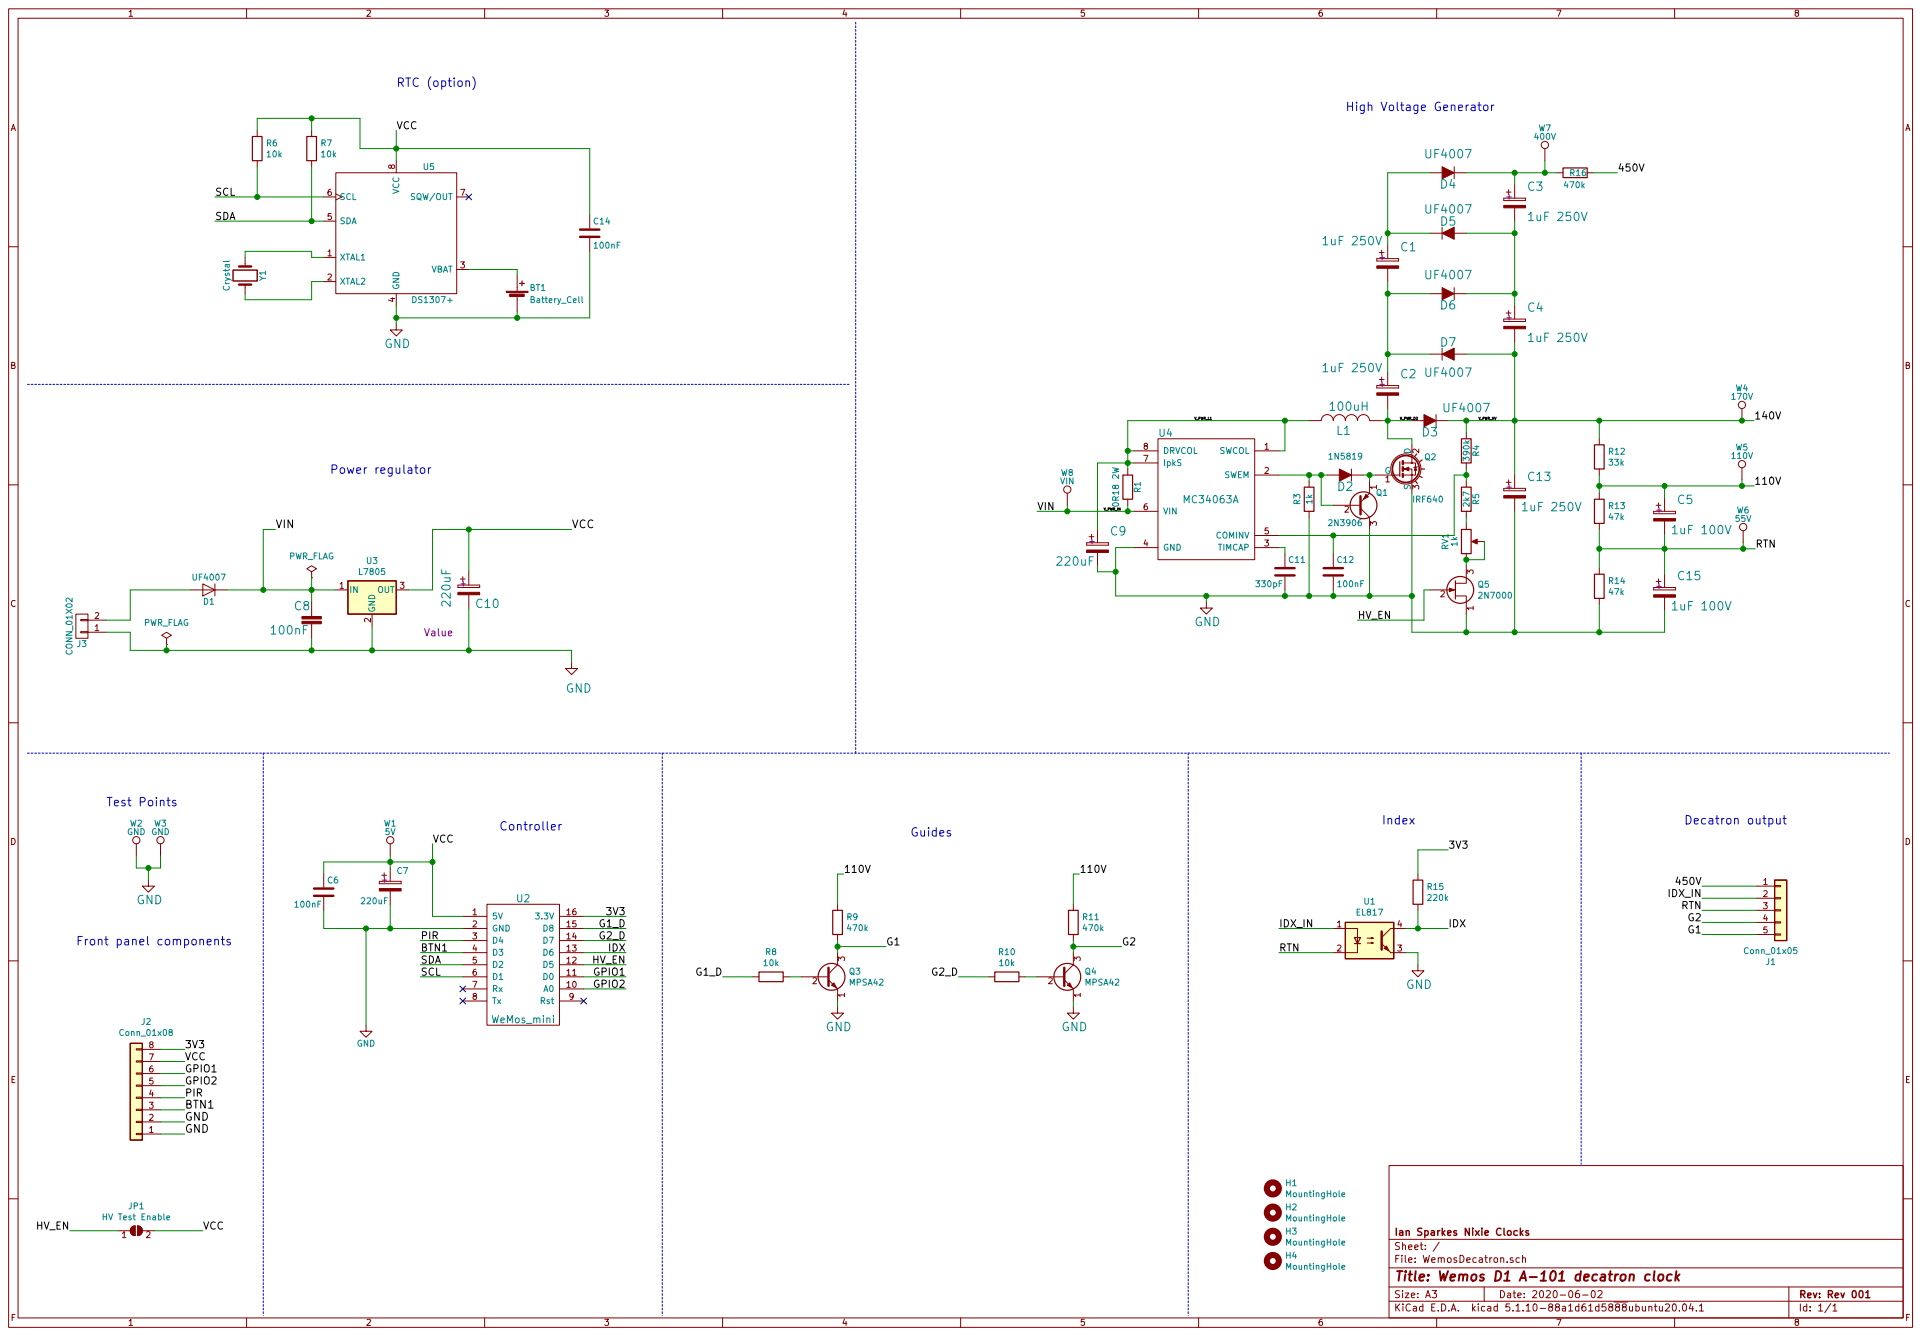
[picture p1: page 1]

4 SDA 5 SCL 6 SQW/OUT VCC 7

Ian Sparkes Nixie Clocks
File: WemosDecatron.sch Sheet: /
Id: 1/1 Title: Wemos D1 A-101 decatron clock

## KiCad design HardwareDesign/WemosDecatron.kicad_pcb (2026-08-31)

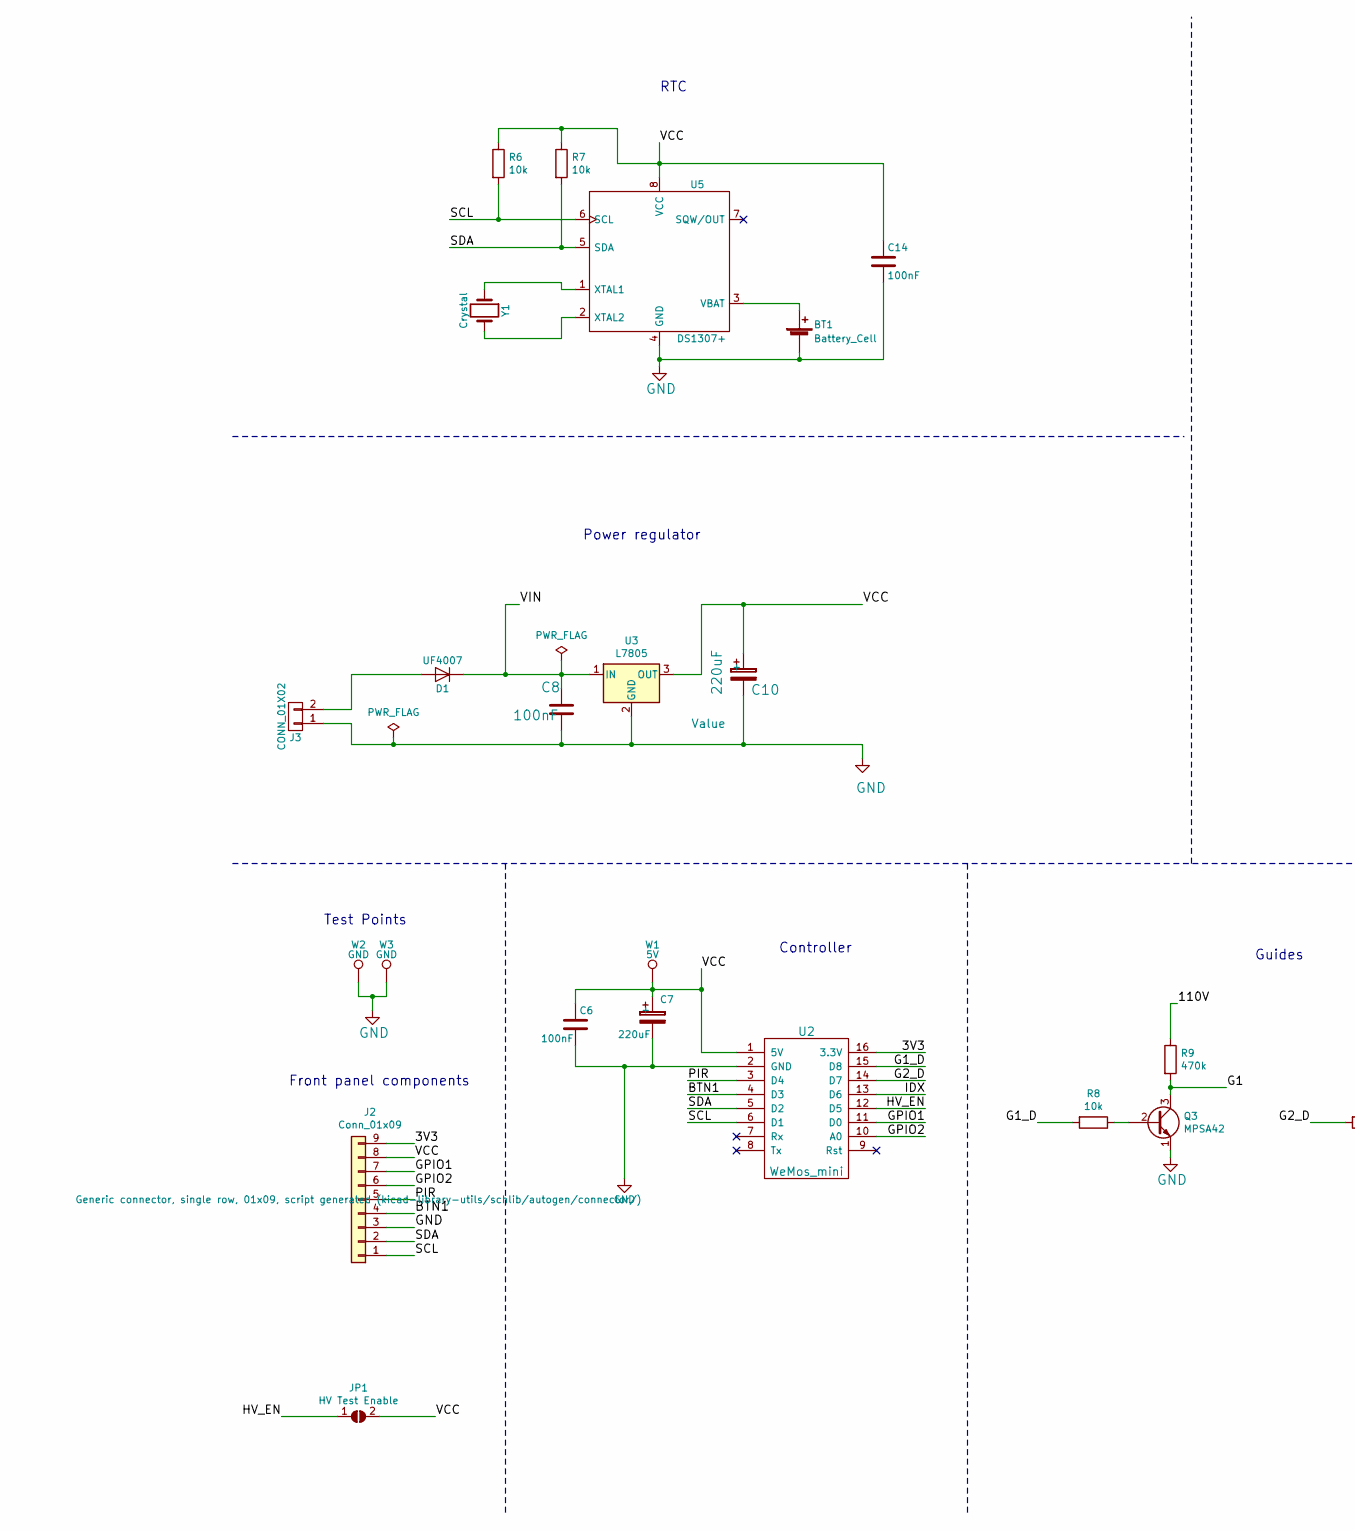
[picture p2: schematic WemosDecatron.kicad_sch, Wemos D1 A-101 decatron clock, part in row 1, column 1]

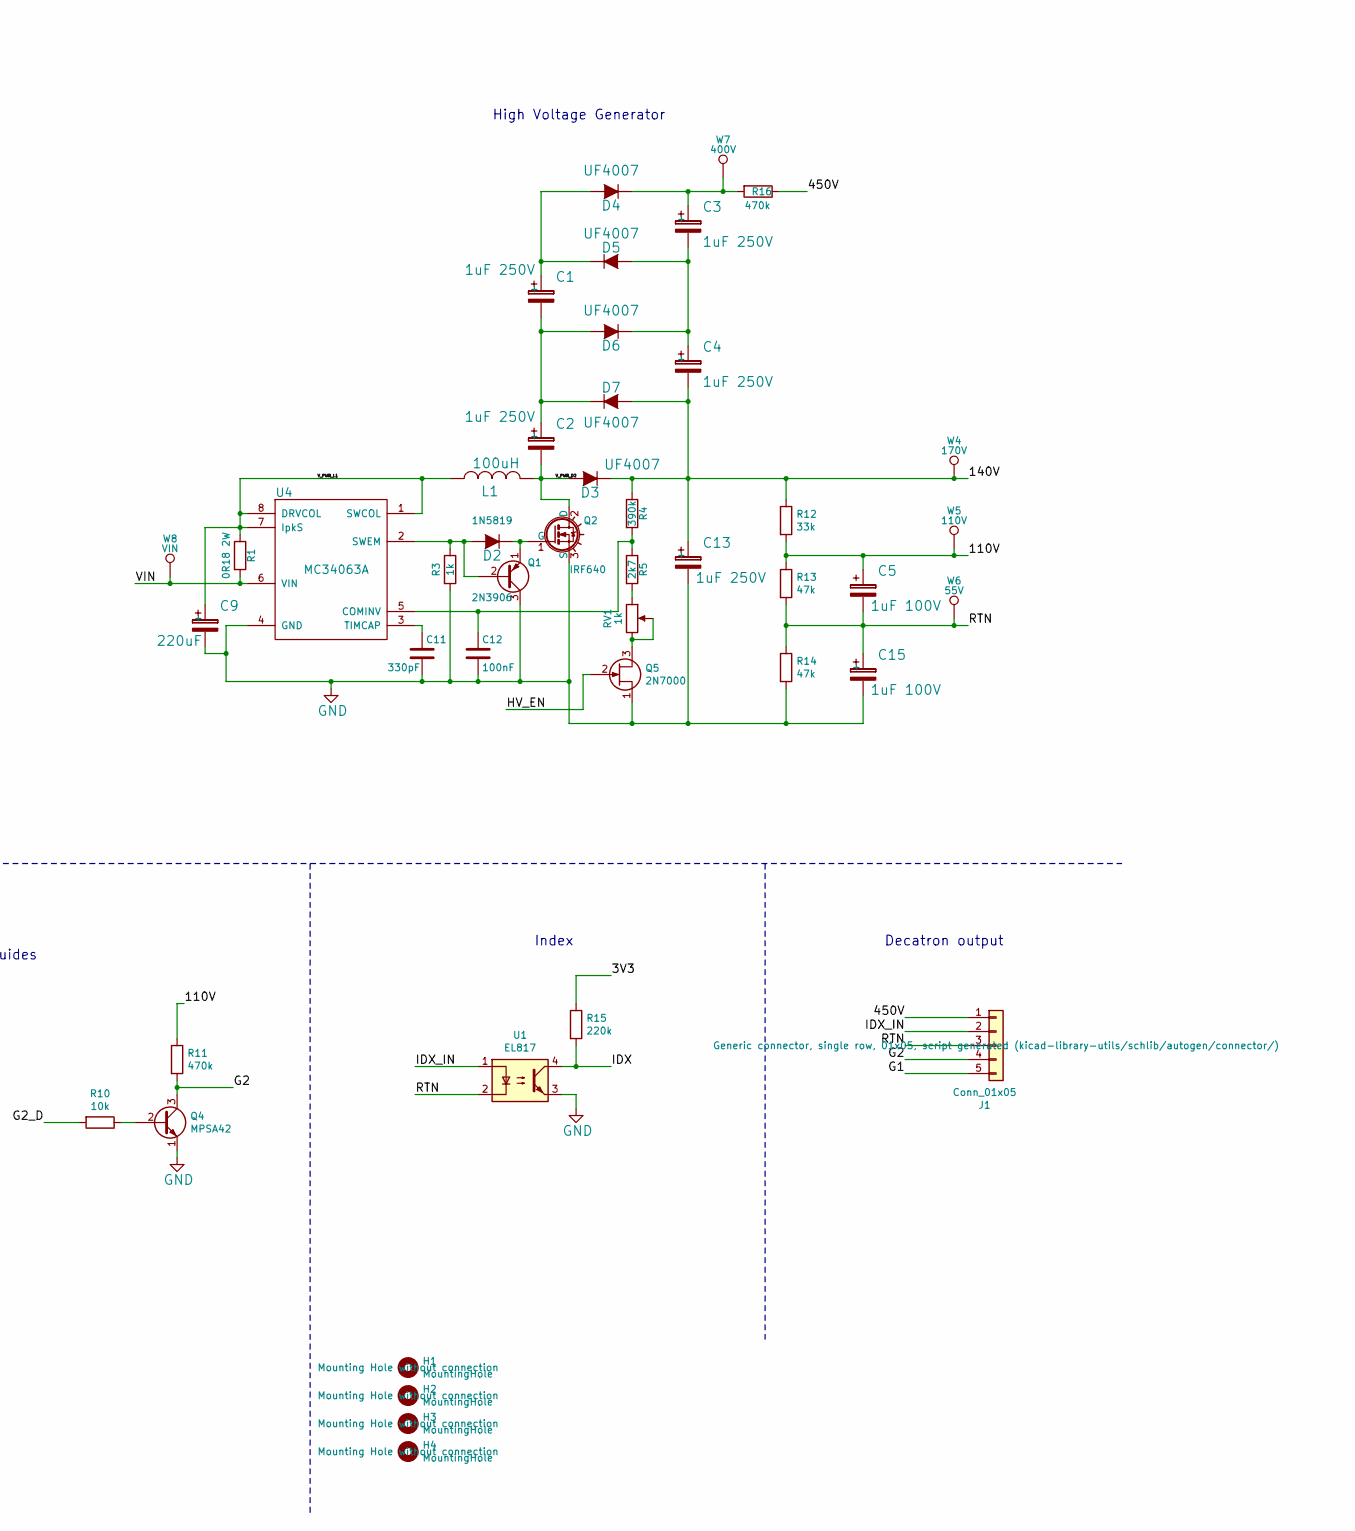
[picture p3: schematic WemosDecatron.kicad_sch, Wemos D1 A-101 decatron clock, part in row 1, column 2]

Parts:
BT1: Battery_Cell; CR1220-CoinCell
C1, C2, C3, C4, C13: 1uF 250V; CP_Radial_D5.0mm_P2.50mm
C5, C15: 1uF 100V; CP_Radial_D5.0mm_P2.50mm
C6, C8, C12, C14: 100nF; C025-024X044
C7, C9, C10: 220uF; C_Radial_D6.3_L11.2_P2.5
C11: 330pF; C025-024X044
D1: UF4007; Diode_DO-41_SOD81_Vertical_AnodeUp
D2: 1N5819; Diode_DO-41_SOD81_Vertical_AnodeUp
D3, D4, D5, D6, D7: UF4007; Diode_DO-41_1N4001
H1, H2, H3, H4: MountingHole; MountingHole_3.2mm_M3
J1: Conn_01x05; Header_MA05-1
J2: Conn_01x09; Header_MA09-1
J3: CONN_01X02; Header_MA02-1
JP1: HV Test Enable; SOLDER-JUMPER
L1: 100uH; Inductor-100mH
Q1: 2N3906; TO-92_inline_2N3906
Q2: IRF640; TO-220-3_H
Q3, Q4: MPSA42; TO-92_inline_MPSA42
Q5: 2N7000; TO-92_inline_2N7000
R1: 0R18 2W; R_2W
R3: 1k; R-0207_2V
R4: 390k; R-0207_2V
R5: 2k7; R-0207_2V
R6, R7, R8, R10: 10k; R-0207_2V
R9, R11, R16: 470k; R-0207_2V
R12: 33k; R-0207_2V
R13, R14: 47k; R-0207_2V
R15: 220k; R-0207_2V
RV1: 1k; Potentiometer_Trimmer_Bourns_3296X
U1: EL817; optocoupler-DIL04
U2: WeMos_mini; WeMos_D1_mini_board_flipped
U3: L7805; TO-220-3_H
U4: MC34063A; MC34063_DIL8
U5: DS1307+; DS1307_DIL8
W1: 5V; TESTPAD_P1-13
W2, W3: GND; TESTPAD_P1-13
W4: 170V; TESTPAD_P1-13
W5: 110V; TESTPAD_P1-13
W6: 55V; TESTPAD_P1-13
W7: 400V; TESTPAD_P1-13
W8: VIN; TESTPAD_P1-13
Y1: Crystal; Crystal_DS10_d1.0mm_l4.3mm_Vertical

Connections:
/3V3: J2.9, R15.1, U2.16 (3.3V)
/110V: C5.1, R9.1, R11.1, R12.2, R13.1, W5.1
/140V: C4.2, C13.1, D3.1 (K), D7.2 (A), R4.1, R12.1, W4.1
/450V: J1.1, R16.1
/BTN1: J2.4, U2.4 (D3)
/G1: J1.5, Q3.3 (C), R9.2
/G1_D: R8.2, U2.15 (D8)
/G2: J1.4, Q4.3 (C), R11.2
/G2_D: R10.2, U2.14 (D7)
/GPIO1: J2.7, U2.11 (D0)
/GPIO2: J2.6, U2.10 (A0)
/HV_EN: JP1.1 (A), Q5.2 (G), U2.12 (D5)
/IDX: R15.2, U1.4, U2.13 (D6)
/IDX_IN: J1.2, U1.1
/PIR: J2.5, U2.3 (D4)
/RTN: C5.2, C15.1, J1.3, R13.2, R14.1, U1.2, W6.1
/SCL: J2.1, R6.2, U2.6 (D1), U5.6 (SCL)
/SDA: J2.2, R7.2, U2.5 (D2), U5.5 (SDA)
/VCC: C6.1, C7.1, C10.1, C14.1, J2.8, JP1.2 (B), R6.1, R7.1, U2.1 (5V), U3.3 (OUT), U5.8 (VCC), W1.1
/VIN: C8.2, D1.1 (K), R1.2, U3.1 (IN), U4.6 (VIN), W8.1
/V_PWR_D2: C2.2, D3.2 (A), L1.2, Q2.2 (D)
/V_PWR_L1: C9.1, L1.1, R1.1, U4.1 (SWCOL), U4.7 (IpkS), U4.8 (DRVCOL)
GND: BT1.2 (-), C6.2, C7.2, C8.1, C9.2, C10.2, C11.2, C12.2, C13.2, C14.2, C15.2, J2.3, J3.1, Q1.3 (C), Q2.3 (S), Q3.1 (E), Q4.1 (E), Q5.1 (S), R3.2, R14.2, U1.3, U2.2 (GND), U3.2 (GND), U4.4 (GND), U5.4 (GND), W2.1, W3.1
unnamed: BT1.1 (+), U5.3 (VBAT)
unnamed: D1.2 (A), J3.2
unnamed: D2.2 (A), Q1.2 (B), R3.1, U4.2 (SWEM)
unnamed: D2.1 (K), Q1.1 (E), Q2.1 (G)
unnamed: C1.1, D4.2 (A), D5.1 (K)
unnamed: C3.1, D4.1 (K), R16.2, W7.1
unnamed: C3.2, C4.1, D5.2 (A), D6.1 (K)
unnamed: C1.2, C2.1, D6.2 (A), D7.1 (K)
unnamed: Q3.2 (B), R8.1
unnamed: Q4.2 (B), R10.1
unnamed: Q5.3 (D), RV1.2, RV1.3
unnamed: R5.2, RV1.1
unnamed: C12.1, R4.2, R5.1, U4.5 (COMINV)
unnamed: C11.1, U4.3 (TIMCAP)
unnamed: U5.1 (XTAL1), Y1.1
unnamed: U5.2 (XTAL2), Y1.2

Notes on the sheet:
Power regulator
Index
Controller
Front panel components
RTC
Decatron output
High Voltage Generator
Guides
Test Points

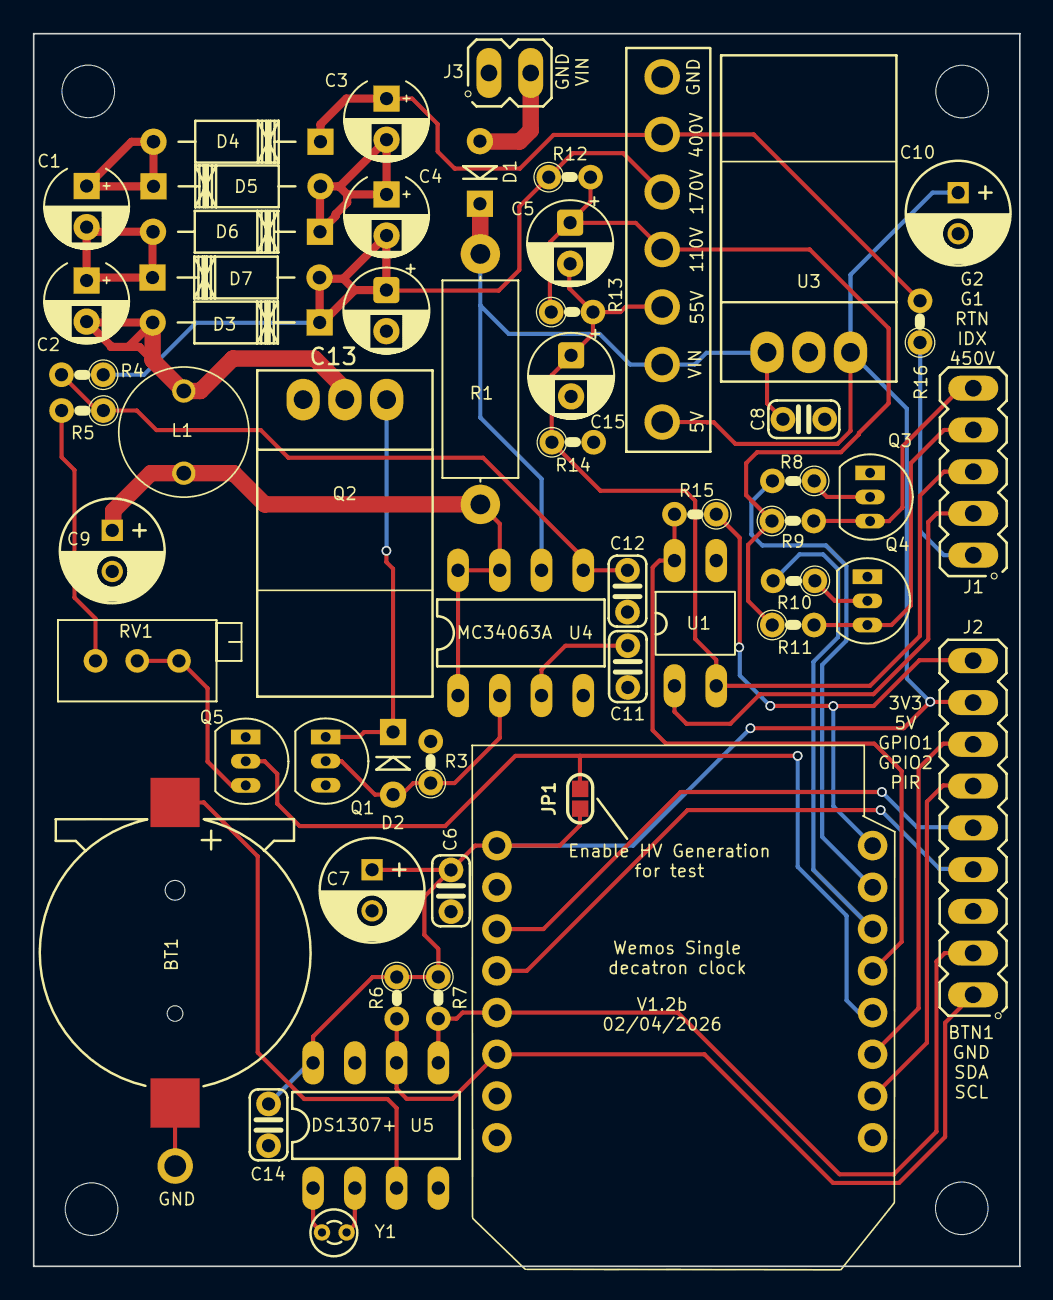
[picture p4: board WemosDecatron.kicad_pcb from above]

Board: 2 copper layers, 60.0 x 75.0 mm, 67 parts (0 on the bottom side), 39 nets.

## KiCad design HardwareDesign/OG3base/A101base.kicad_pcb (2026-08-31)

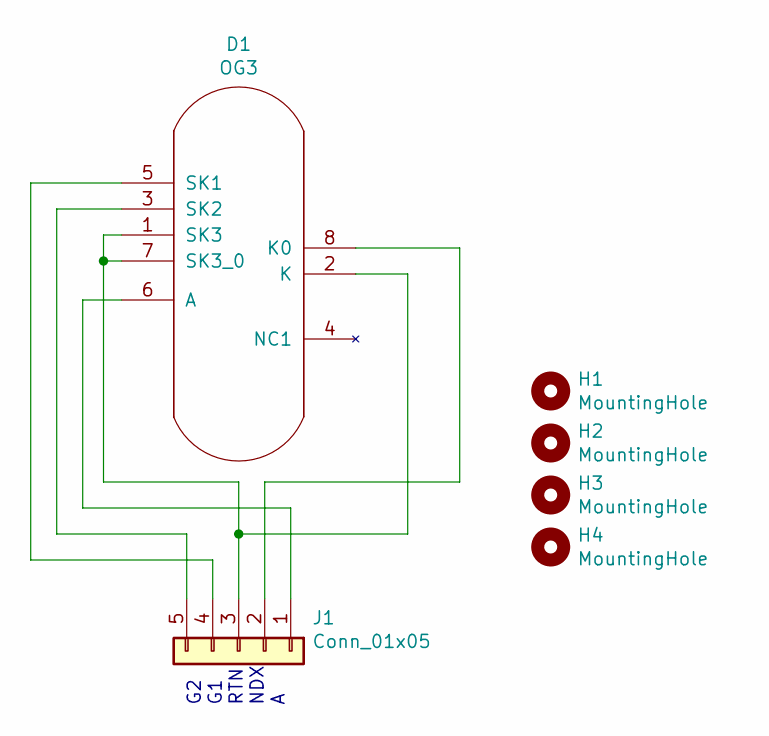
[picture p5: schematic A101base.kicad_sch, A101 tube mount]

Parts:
D1: OG3; OG4
H1, H2, H3, H4: MountingHole; MountingHole_3.2mm_M3
J1: Conn_01x05; Header_MA05-1

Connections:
unnamed: D1.1 (SK3), D1.2 (K), D1.7 (SK3_0), J1.3
unnamed: D1.3 (SK2), J1.5
unnamed: D1.5 (SK1), J1.4
unnamed: D1.6 (A), J1.1
unnamed: D1.8 (K0), J1.2

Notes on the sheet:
G2 G1 RTN NDX A

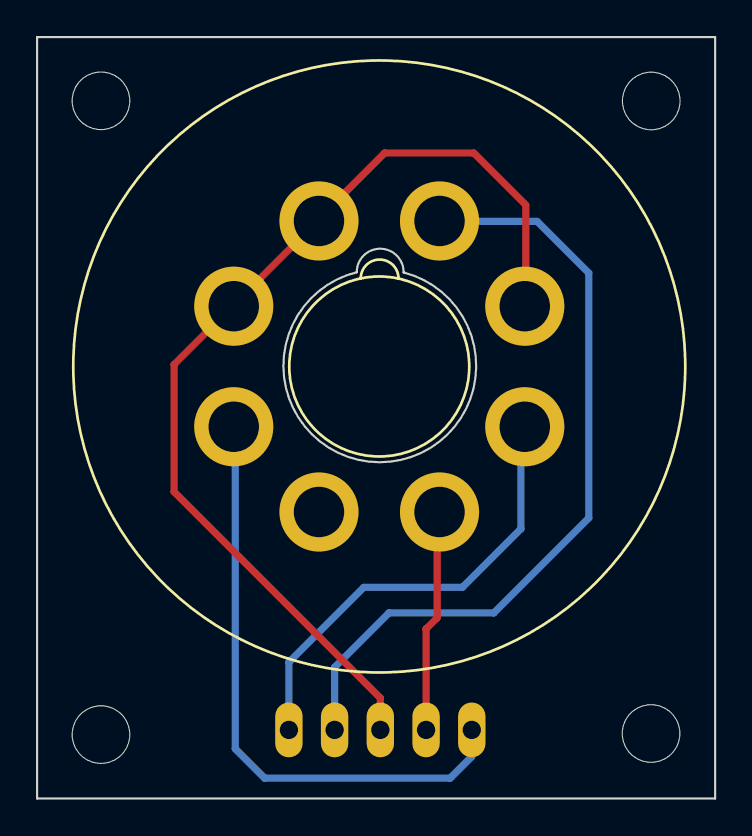
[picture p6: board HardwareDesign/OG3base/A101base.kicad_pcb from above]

Board: 2 copper layers, 37.7 x 42.3 mm, 6 parts (1 on the bottom side), 5 nets.

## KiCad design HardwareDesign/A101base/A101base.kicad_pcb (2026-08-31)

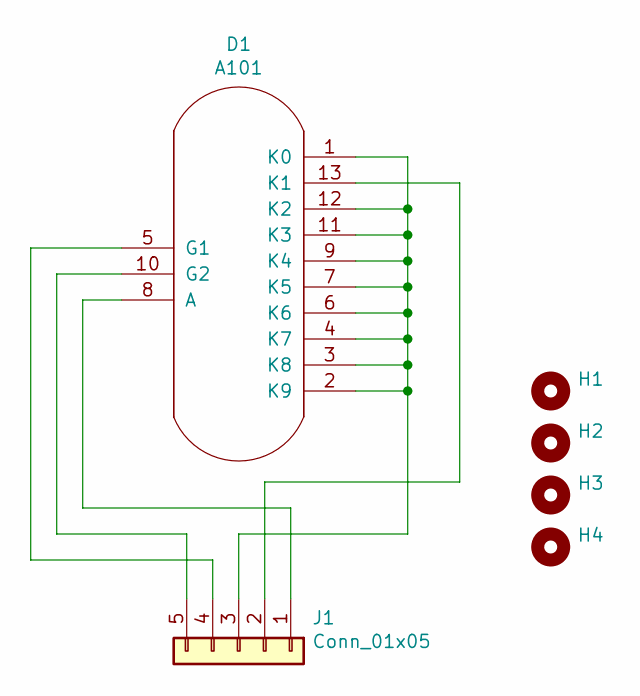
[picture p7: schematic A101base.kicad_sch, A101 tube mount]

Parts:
D1: A101; A101-TopView
H1, H2, H3, H4: MountingHole; MountingHole_3.2mm_M3
J1: Conn_01x05; Header_MA05-1

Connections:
unnamed: D1.1 (K0), D1.2 (K9), D1.3 (K8), D1.4 (K7), D1.6 (K6), D1.7 (K5), D1.9 (K4), D1.11 (K3), D1.12 (K2), J1.3
unnamed: D1.5 (G1), J1.4
unnamed: D1.8 (A), J1.1
unnamed: D1.10 (G2), J1.5
unnamed: D1.13 (K1), J1.2

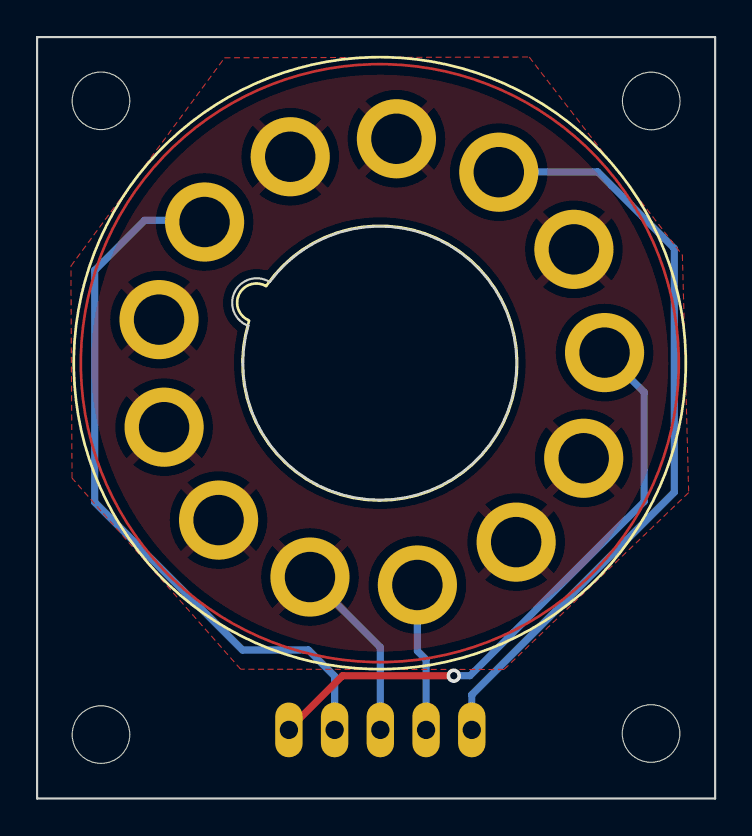
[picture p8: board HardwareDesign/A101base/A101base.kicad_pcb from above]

Board: 2 copper layers, 37.7 x 42.3 mm, 6 parts (1 on the bottom side), 5 nets.

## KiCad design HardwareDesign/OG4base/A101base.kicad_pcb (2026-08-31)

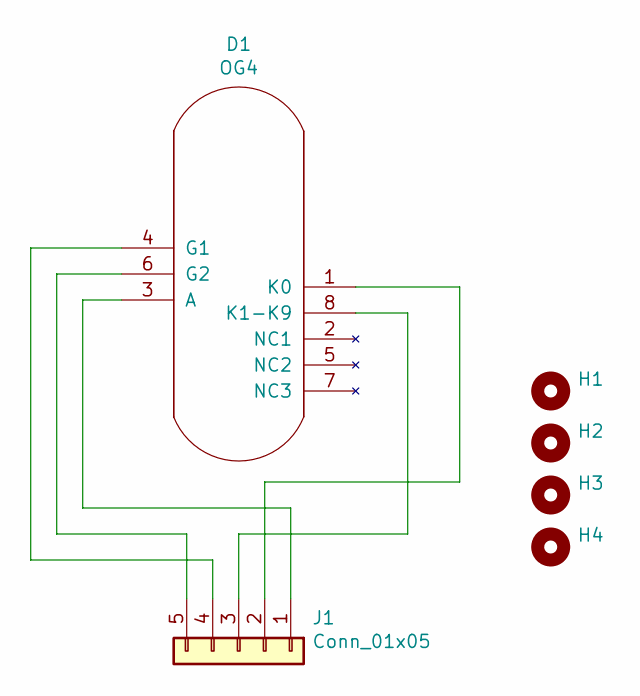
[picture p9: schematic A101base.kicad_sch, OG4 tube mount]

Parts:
D1: OG4
H1, H2, H3, H4: MountingHole; MountingHole_3.2mm_M3
J1: Conn_01x05; Header_MA05-1

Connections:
unnamed: D1.1 (K0), J1.2
unnamed: D1.3 (A), J1.1
unnamed: D1.4 (G1), J1.4
unnamed: D1.6 (G2), J1.5
unnamed: D1.8 (K1-K9), J1.3

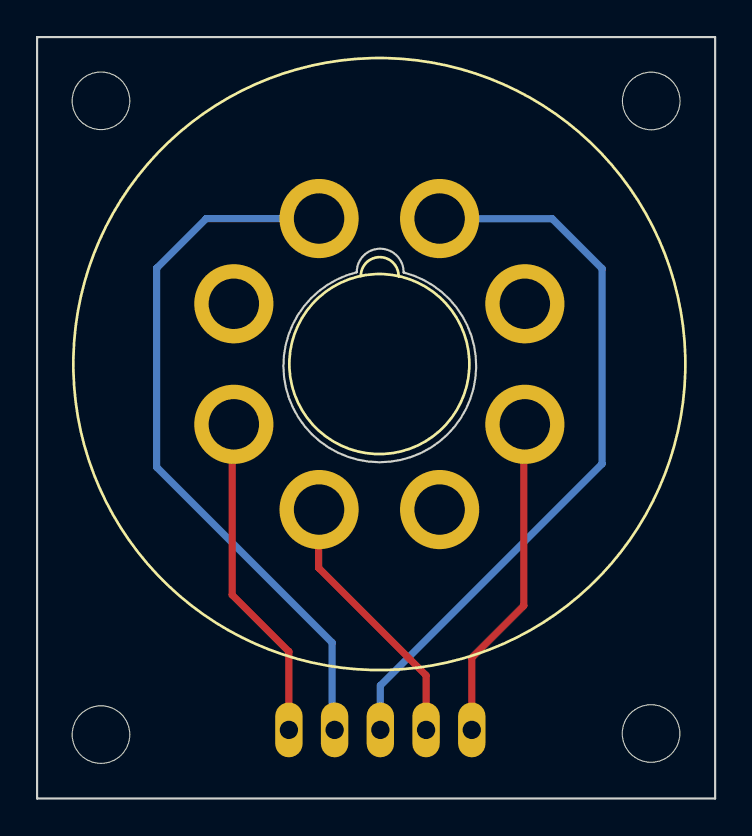
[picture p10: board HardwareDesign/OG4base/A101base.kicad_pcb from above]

Board: 2 copper layers, 37.7 x 42.3 mm, 6 parts (1 on the bottom side), 5 nets.

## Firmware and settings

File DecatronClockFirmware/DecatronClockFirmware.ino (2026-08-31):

//**********************************************************************************
//* Code for a Single Decatron Spinner based clock.                                *
//*                                                                                *
//*  nixie@protonmail.ch                                                           *
//*                                                                                *
//* Board: Lolin(Wemos) D1 R2 & Mini                                               *
//* CPU-Frequency: 160MHz                                                           *
//* Flash Size: 4MB (FS: 2MB, OTA:~1019KB)                                         *
//*                                                                                *
//**********************************************************************************
//**********************************************************************************

#include <TimeLib.h>            // http://playground.arduino.cc/code/time (Margolis 1.5.0) // https://github.com/michaelmargolis/arduino_time
#include <WiFiManager.h>        // https://github.com/tzapu/WiFiManager  (tzapu 0.14.0)

#include "ClockButton.h"
#include "ClockUtils.h"
#include "DebugManager.h"
#include "ESP_DS1307.h"
#include "HtmlServer.h"
#include "NtpAsync.h"
#include "SPIFFS.h"

#define DEBUG     false

// ------------------ I2C Slave Protocol ----------------
// Receives 4 bytes from master once per second:
//   Byte 1: Hours   (0-23)
//   Byte 2: Minutes (0-59)
//   Byte 3: Seconds (0-59)
//   Byte 4: Control
//     Bit 0:   Blanked (1 = display is blanked)
//     Bits 1-4: Primary display mode (from master)
// ------------------------------------------------------

#define DECATRON_SLAVE_I2C_ADDRESS  106
#define DECATRON_CTRL_BLANKED       0x01

// ------------------ Decatron Control ----------------

#define INT_MUX_COUNTS_ON   1000
#define INT_MUX_COUNTS_OFF  250000

volatile byte digitStep = 0;
volatile byte phaseStep = 0;
volatile byte indexMark = 0;

volatile uint32_t muxCount = INT_MUX_COUNTS_ON;
volatile uint32_t muxCountSecs = muxCount * 5;
volatile uint32_t muxCountMins = muxCount * 15;
volatile uint32_t muxCountHours = muxCount * 60;

int startupDelay = INT_MUX_COUNTS_ON * 150;

byte displayHours = 0;
byte displayMinsPrep = 0;   // prepared before flash status
byte displaySecsPrep = 0;   // prepared before flash status
byte displayMins = 0;
byte displaySecs = 0;
volatile int millisInSecond = 0;

// ------------------ Usage statistics -----------------

int impressionsPerSec = 0;
int lastImpressionsPerSec = 0;

// ----------------- Real time clock -------------------

byte useRTC = false;  // true if we detect an RTC
boolean onceHadAnRTC = false;

// ------------- Time management variables -------------

unsigned long nowMillis = 0;
unsigned long lastCheckMillis = 0;
unsigned long lastSecMillis = nowMillis;
unsigned long lastSecond = second();  
boolean secondsChanged = false;
boolean triggeredThisSec = false;
long restartAtMillis = 0;
boolean restartResetWifi = false;

// ----------------- Motion detector -------------------

unsigned long pirLastSeen = 0;
boolean pirInstalled = false;
int pirConsecutiveCounts = 300;  // set with a high value to stop the PIR being falsely detected the first time round the loop
boolean pirStatus = false;

// --------------------- Blanking ----------------------

boolean blanked = false;
byte blankSuppressStep = 0;    // The press we are on: 1 press = suppress for 1 min, 2 press = 1 hour, 3 = 1 day
unsigned long blankSuppressedMillis = 0;   // The end time of the blanking, 0 if we are not suppressed
unsigned long blankSuppressedSelectionTimoutMillis = 0;   // Used for determining the end of the blanking period selection timeout
unsigned int spinUpVal = 0;

// --------------------- I2C Slave -----------------

volatile bool i2cDataReceived = false;
volatile byte i2cHour = 0;
volatile byte i2cMin  = 0;
volatile byte i2cSec  = 0;
volatile byte i2cCtrl = 0;

// --------------------- Misc ----------------------

bool debugVal = DEBUG;

// ----------------------- Components ----------------------------

ClockButton button1(inputPin1, CLOCK_BUTTON_ACTIVE_LO);

// ************************************************************
// Interrupt routine for scheduled interrupts
// Spin through each of the pins on the decatron, using a short
// interrupt time for "off" pins (not really off, but quite dim)
// and longer dwell times for the lit pins.
// ************************************************************
ICACHE_RAM_ATTR void displayUpdate() {
  uint32_t delayCount = muxCount;
  phaseStep++;

  if (phaseStep == 3) {
    phaseStep = 0;
    digitStep++;
    if (digitStep==10){
      digitStep = 0;
    }
  }

  G_step(phaseStep);

  byte pinStep = digitStep*3+phaseStep;

  if (pinStep == displayHours) {
    delayCount = muxCountHours;
  } else if (pinStep == displayMins) {
    delayCount = muxCountMins;
  } else if (pinStep == displaySecs) {
    delayCount = muxCountSecs;
  }

  timer1_write(delayCount);
}

// ************************************************************
// Interrupt routine for scheduled interrupts while scanning
// Spin through each of the pins on the decatron, using a short
// interrupt time for "off" pins (not really off, but quite dim)
// and longer dwell times for the lit pins.
// ************************************************************
ICACHE_RAM_ATTR void displayUpdateScanning() {
  phaseStep++;

  if (phaseStep == 3) {
    phaseStep = 0;
    digitStep++;
    if (digitStep==10){
      digitStep = 0;
    }
  }

  G_step(phaseStep);

  timer1_write(startupDelay);
}

// ************************************************************
// Perform the actual step
// ************************************************************
ICACHE_RAM_ATTR void G_step(int CINT)
{
  if (CINT == 0)
  {
    digitalWrite(Guide1, LOW);
    digitalWrite(Guide2, LOW);
  }
  if (CINT == 1)
  {
    digitalWrite(Guide1, HIGH);
    digitalWrite(Guide2, LOW);
  }
  if (CINT == 2)
  {
    digitalWrite(Guide1, LOW);
    digitalWrite(Guide2, HIGH);
  }
}

// ************************************************************
// Detect the falling edge of the Index pin and get the index
// value - adjust it to allow the display to rotate
// ************************************************************
ICACHE_RAM_ATTR void indexMarkTrigger() {
  indexMark = digitStep;
  if (digitStep != current_config.displayRotate) {
    digitStep--;
    if (digitStep > 9) {
      digitStep = 9;
    }
  }
}

// ************************************************************
// I2C slave receive callback - called from interrupt context.
// Reads 4 bytes: hours, minutes, seconds, control.
// ************************************************************
void ICACHE_RAM_ATTR onI2CReceive(int numBytes) {
  if (numBytes >= 4) {
    i2cHour = Wire.read();
    i2cMin  = Wire.read();
    i2cSec  = Wire.read();
    i2cCtrl = Wire.read();
    while (Wire.available()) Wire.read();
    i2cDataReceived = true;
  } else {
    while (Wire.available()) Wire.read();
  }
}

// ----------------------------------------------------------------------------------------------------
// ----------------------------------------------  Set up  --------------------------------------------
// ----------------------------------------------------------------------------------------------------
void setup() {
  debugManager.setUp(debugVal);

  pinMode(Guide1, OUTPUT);
  pinMode(Guide2, OUTPUT);
  pinMode(Index, INPUT_PULLUP);
  pinMode(HVEnable, OUTPUT);
  digitalWrite(HVEnable, HIGH);

  debugManager.debugMsg("Starting display interrupt handler for scanning");

  attachInterrupt(digitalPinToInterrupt(Index), indexMarkTrigger, FALLING);

  startupDelay = INT_MUX_COUNTS_OFF * 2;
  timer1_attachInterrupt(displayUpdateScanning);
  timer1_enable(TIM_DIV16, TIM_EDGE, TIM_SINGLE);
  timer1_write(startupDelay);

  debugManager.debugMsg("Started");

  WiFiManager wifiManager;
  wifiManager.setDebugOutput(debugVal);

  // set up the NTP component and wire up the "got time update" callback
  ntpAsync.setUp();
  NewTimeCallback ntcb = newTimeUpdateReceived;
  ntpAsync.setNewTimeCallback(ntcb);

  DebugCallback dbcb = debugMsgLocal;
  ntpAsync.setDebugCallback(dbcb);
  ntpAsync.setDebugOutput(debugVal);

  // Start I2C as slave so the Eniac master can send us time updates.
  // SDA = D2 = GPIO4, SCL = D1 = GPIO5.
  // Note: slave mode prevents us acting as I2C master (RTC not accessible).
  Wire.begin(DECATRON_SLAVE_I2C_ADDRESS);
  Wire.onReceive(onI2CReceive);
  debugManager.debugMsg("I2C slave started at address " + String(DECATRON_SLAVE_I2C_ADDRESS));

  button1.reset();

  // Let the user do the factory reset if required
  delay(1000);

  for (int i = 0; i < 25 ; i++) button1.checkButton(millis());

  if (button1.isButtonPressedNow()) {
    factoryReset();
    delay(1000);
    ESP.restart();
  }

  if (!spiffs.getConfigFromSpiffs(&current_config)) {
    if (spiffs.testMountSpiffs()) {
      debugManager.debugMsg("No config found - resetting everything");
      factoryReset();
    } else {
      debugManager.debugMsg("Could not mount SPIFFS - flashing error?");
    }
  } else {
    debugManager.debugMsg("Loaded SPIFFS");

    setWebAuthentication(current_config.webAuthentication);
    setWebUserName(current_config.webUsername);
    setWebPassword(current_config.webPassword);

    ntpAsync.setTZS(current_config.tzs);
    ntpAsync.setNtpPool(current_config.ntpPool);
    ntpAsync.setUpdateInterval(current_config.ntpUpdateInterval);
  }

  setSpinUpVal();

  debugManager.debugMsg("Starting AP as " + WiFi.hostname() + "/SetMeUp!");
  wifiManager.setConfigPortalTimeout(CONFIG_PORTAL_TIMEOUT);
  wifiManager.setAPCallback(configModeCallback);

  startupDelay = INT_MUX_COUNTS_OFF;

  boolean connected = false;
  connected = wifiManager.autoConnect("decatron", "SetMeUp!");

  if (connected) {
    debugManager.debugMsg("Connected!");
  }

  IPAddress apIP = WiFi.softAPIP();
  IPAddress myIP = WiFi.localIP();
  debugManager.debugMsg("AP IP address: " + formatIPAsString(apIP));
  debugManager.debugMsg("IP address: " + formatIPAsString(myIP));

  // If we lose the connection, we try to recover it
  WiFi.setAutoReconnect(true);

  // See if we can already get the time
  ntpAsync.getTimeFromNTP();

  long startSearchMs = millis();
  bool needUpdate = true;
  while (((millis() - startSearchMs) < 10000) && needUpdate) {
    delay(1000);
    ntpAsync.getTimeFromNTP();
    if (ntpAsync.ntpTimeValid(millis()) > 0) {
      debugManager.debugMsg("Got update from NTP, exiting loop");
      needUpdate = false;
    }
  }

  setServerPageHandlers();
  server.begin();
  debugManager.debugMsg("HTTP server started");

  if (getOTAvailable()) {
    debugManager.debugMsg("Can do OTA: sketch size ("+String(ESP.getSketchSize())+"), flash size ("+String(ESP.getFlashChipRealSize())+")");
    httpUpdater.setup(&server, "/update", "admin", "update");
  } else {
    debugManager.debugMsg("NO OTA: sketch size ("+String(ESP.getSketchSize())+"), flash size ("+String(ESP.getFlashChipRealSize())+")");
  }

  if (mdns.begin(WiFi.hostname(), WiFi.localIP())) {
    debugManager.debugMsg("MDNS responder started as http://" + WiFi.hostname() + ".local");
    mdns.addService("http", "tcp", 80);
  }

  // setPIRPullup(current_config.usePIRPullup);

  // initialise the internal time (in case we don't find the time provider)
  nowMillis = millis();

  // RTC is not accessible while in I2C slave mode; time comes from master.
  useRTC = false;
  onceHadAnRTC = false;

  debugManager.debugMsg("Exit startup");
  spiffs.getStatsFromSpiffs(&current_stats);

  muxCount = INT_MUX_COUNTS_OFF;
  
  timer1_attachInterrupt(displayUpdate);
}

void setSpinUpVal(){
  switch (current_config.spinUpSpeed) {
    case SPIN_UP_SLOW: {
      spinUpVal = 200;
      break;
    }
    case SPIN_UP_MEDIUM: {
      spinUpVal = 100;
      break;
    }
    case SPIN_UP_FAST: {
      spinUpVal = 50;
      break;
    }
  }
}

// the loop function runs over and over again forever
void loop() {
  server.handleClient();
  mdns.update();

  nowMillis = millis();

  // shows us how fast the inner loop is running
  impressionsPerSec++;

  // -------------------------------------------------------------------------------

  if (lastSecond != second()) {
    lastSecond = second();
    lastSecMillis = nowMillis;
    secondsChanged = true;
    performOncePerSecondProcessing();

    if ((second() == 0) && (!triggeredThisSec)) {
      if ((minute() == 0)) {
        if (hour() == 0) {
          performOncePerDayProcessing();
        }
        performOncePerHourProcessing();
      }
      performOncePerMinuteProcessing();
    }

    // Make sure we don't call multiple times
    triggeredThisSec = true;

    if ((second() > 0) && triggeredThisSec) {
      triggeredThisSec = false;
    }
  }

  if (digitalRead(pirPin) == HIGH) {
    pirConsecutiveCounts++;
  }

  millisInSecond = nowMillis - lastSecMillis;

  if (current_config.flashSeconds) {
    if (current_config.showSeconds) {
      if (millisInSecond > 500) {
        displayMins = displayMinsPrep;
      } else {
        displayMins = 255;
      }
      if ((millisInSecond / 100) % 2 == 0) {
        displaySecs = displaySecsPrep;
      } else {
        displaySecs = 255;
      }
    }
  } else {
    displayMins = displayMinsPrep;
    displaySecs = displaySecsPrep;
  }

  // Apply time and blanking received from the Eniac master.
  // This overrides the NTP-based values set in performOncePerSecondProcessing().
  if (i2cDataReceived) {
    i2cDataReceived = false;
    int adjustedHour = (i2cHour % 12) * 60 + i2cMin;
    float hourFloat = adjustedHour * 30.0 / 720;
    displayHours    = (byte) hourFloat;
    displayMinsPrep = i2cMin / 2;
    displaySecsPrep = i2cSec / 2;
    blanked = (i2cCtrl & DECATRON_CTRL_BLANKED) != 0;
  }

  if (blanked) {
    if (muxCount < INT_MUX_COUNTS_OFF) {
      muxCount += 500;
    } else {
      digitalWrite(HVEnable, false);
    }
  } else {
    digitalWrite(HVEnable, true);
    if (muxCount > INT_MUX_COUNTS_ON) {
      muxCount -= (((muxCount-INT_MUX_COUNTS_ON)/spinUpVal) + 1);
      if (muxCount < INT_MUX_COUNTS_ON) muxCount = INT_MUX_COUNTS_ON;
    }
  }

  // help index location
  if (indexMark != current_config.displayRotate) {
    muxCount = INT_MUX_COUNTS_ON * 200;
  }

  delay(10);
}

// ************************************************************
// Called once per second
// ************************************************************
void performOncePerSecondProcessing() {
  // Store the current value and reset
  lastImpressionsPerSec = impressionsPerSec;
  impressionsPerSec = 0;

  boolean pirBlanked = checkPIR(nowMillis);
  boolean nativeBlanked = checkBlanking();

  // Check if we are in blanking suppression mode
  blanked = (nativeBlanked || pirBlanked) && (blankSuppressedMillis == 0);

  if (blanked) {
    debugManager.debugMsg("blanked");
    if (pirBlanked)
    debugManager.debugMsg(" -> PIR");
    if (nativeBlanked)
      debugManager.debugMsg(" -> Native");
  }

  // reset the blanking period selection timer
  if (nowMillis > blankSuppressedSelectionTimoutMillis) {
    blankSuppressedSelectionTimoutMillis = 0;
    blankSuppressStep = 0;
  }

  if (ntpAsync.getNextUpdate(nowMillis) < 0) {
    ntpAsync.getTimeFromNTP();
  }

  // get hour dot, from hours (0-23) mod 12, plus minutes, so we end
  // up with a value in the range of 0 (00:00) to 719 (11:59)
  int adjustedHour = (hour() % 12) * 60 + minute();
  
  float hourFloat = adjustedHour * 30.0 / 720;
  displayHours = (byte) hourFloat;
  displayMinsPrep = minute()/2;

  if (current_config.showSeconds) {
    displaySecsPrep = second()/2;
  } else {
    displaySecsPrep = 255;
  }

  // Async restart
  if (restartAtMillis > 0) {
    restartAtMillis -=1000;
    if (restartAtMillis <= 0) {
      if (restartResetWifi) {
        WiFiManager wifiManager;
        wifiManager.resetSettings();
        delay(500);
      }
      ESP.restart();
    }
  }
}

// ************************************************************
// Called once per minute
// ************************************************************
void performOncePerMinuteProcessing() {
  debugManager.debugMsg("---> OncePerMinuteProcessing");

  debugManager.debugMsg("nu: " + String(ntpAsync.getNextUpdate(nowMillis)));

  // RTC sync skipped: Wire is in slave mode; time comes from I2C master.

  // Usage stats
  current_stats.uptimeMins++;

  if (!blanked) {
    current_stats.tubeOnTimeMins++;
  }

  // RTC - light up only if we have lost our RTC
  if (onceHadAnRTC && !useRTC) {
    // debugManager.debugMsg("lost access to RTC");
  }

  if (getIsConnected()) {
    IPAddress ip = WiFi.localIP();
    debugManager.debugMsg("IP: " + formatIPAsString(ip));
  } else {
    IPAddress ip = WiFi.localIP();
    debugManager.debugMsg("Not connected IP: " + formatIPAsString(ip));
  }
}

// ************************************************************
// Called once per hour
// ************************************************************
void performOncePerHourProcessing() {
  debugManager.debugMsg("---> OncePerHourProcessing");
  reconnectDroppedConnection();
}

// ************************************************************
// Called once per day
// ************************************************************
void performOncePerDayProcessing() {
  debugManager.debugMsg("---> OncePerDayProcessing");
  spiffs.saveStatsToSpiffs(&current_stats);
}


// ************************************************************
// Callback: When the NTP component tells us there is an update
// go and get it
// ************************************************************
void newTimeUpdateReceived() {
  debugManager.debugMsg("Got a new time update");
  setTimeFromServer(ntpAsync.getLastTimeFromServer());
  setRTCTime();
}

// ************************************************************
// Set the time from the value we get back from the timer server
// ************************************************************
void setTimeFromServer(String timeString) {
  int intValues[6];
  grabInts(timeString, &intValues[0], ",");
  setTime(intValues[SYNC_HOURS], intValues[SYNC_MINS], intValues[SYNC_SECS], intValues[SYNC_DAY], intValues[SYNC_MONTH], intValues[SYNC_YEAR]);
  debugManager.debugMsg("Set internal time to NTP time: " + String(year()) + ":" + String(month()) + ":" + String(day()) + " " + String(hour()) + ":" + String(minute()) + ":" + String(second()));
}

//**********************************************************************************
//**********************************************************************************
//*                         RTC Module Time Provider                               *
//**********************************************************************************
//**********************************************************************************

// ************************************************************
// Get the time from the RTC
// ************************************************************
String getRTCTime(boolean setInternalTime) {
  testRTCTimeProvider();
  if (useRTC) {
    Clock.getTime();
    int years = Clock.year + 2000;
    byte months = Clock.month;
    byte days = Clock.dayOfMonth;
    byte hours = Clock.hour;
    byte mins = Clock.minute;
    byte secs = Clock.second;

    String returnValue = String(years) + ":" + String(months) + ":" + String(days) + " " + String(hours) + ":" + String(mins) + ":" + String(secs);
    debugManager.debugMsg("Got RTC time: " + returnValue);

    if (setInternalTime) {
      // Set the internal time provider to the value we got
      setTime(hours, mins, secs, days, months, years);
      debugManager.debugMsg("Set Internal time to: " + returnValue);
    }

    return returnValue;
  }
}

// ************************************************************
// Check that we still have access to the time from the RTC
// ************************************************************
void testRTCTimeProvider() {
  // Set up the time provider
  // first try to find the RTC, if not available, go into slave mode
  Wire.beginTransmission(RTC_I2C_ADDRESS);
  useRTC = (Wire.endTransmission() == 0);
}

// ************************************************************
// Set the date/time in the RTC from the internal time
// Always hold the time in 24 format, we convert to 12 in the
// display.
// ************************************************************
void setRTCTime() {
  testRTCTimeProvider();
  if (useRTC) {
    Clock.fillByYMD(year() % 100, month(), day());
    Clock.fillByHMS(hour(), minute(), second());
    Clock.setTime();

    debugManager.debugMsg("Set RTC time to internal time: " + String(year()) + ":" + String(month()) + ":" + String(day()) + " " + String(hour()) + ":" + String(minute()) + ":" + String(second()));
  }
}

// ************************************************************
// Local debug routine
// ************************************************************
void debugMsgLocal(String message) {
  debugManager.debugMsg(message);
}

// ************************************************************
// See if we have enough flash space for OTA
// ************************************************************
boolean getOTAvailable() {
  return ESP.getSketchSize()*2 < ESP.getFlashChipRealSize();
}

// ----------------------------------------------------------------------------------------------------
// ----------------------------------------- Network handling -----------------------------------------
// ----------------------------------------------------------------------------------------------------

// ************************************************************
// What it says on the tin
// ************************************************************
boolean getIsConnected() {
  return WiFi.isConnected();
}
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
